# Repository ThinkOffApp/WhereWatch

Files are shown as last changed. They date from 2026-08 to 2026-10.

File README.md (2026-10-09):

# WhereWatch

**A pendant that remembers where you left things — fully local.** A tiny
wearable camera photo-logs your day into a Raspberry Pi at home; a local
vision model watches the trail. Ask *"where are my keys?"* and get back the
last photo that contains them, with a timestamp. No cloud, no subscription,
nothing leaves your house.

## Two devices. Zero cloud.

Plug in the Raspberry Pi. Charge the pendant over USB-C. Wear it.
That is the whole system. CodeWatch is the phone and watch dashboard for the same local *Watch family.

WhereWatch remembers where you placed your things, privately. The Pi stores
a photo of the last useful observation of an item, together with its time and
location. If people appear in a retained image, faces are blurred before that
image becomes part of the memory store.

- **No cloud service required**
- **No subscription required**
- **No video stored**
- **No face identification**
- **Faces blurred before retained images are written to storage**
- **Object-location history stays on the Pi in your home**

The product target is deliberately small: **pendant + Raspberry Pi**. A large
GPU box, desktop, NAS, M5 cluster, or hosted AI service may be useful for
experiments, but none is part of the required product architecture.

Sibling of [CarWatch](https://github.com/ThinkOffApp/CarWatch) (your car as a
team-chat agent), [ClawWatch](https://github.com/ThinkOffApp/ClawWatch)
(health on your wrist) and [CodeWatch](https://codewatch.app) (your agents on
your phone). This one watches where things went.

## Status — honesty first

**Design stage. Nothing here is built yet.** This README is the agreed
design; code lands as it is written and every feature will be labeled
*proven / built + tested / planned*, the same policy as CarWatch.

## The product principle

**Two objects, simple power.** The whole system is a pendant you wear and a Pi
box. The Pi stays plugged into power; the pendant charges over USB-C and runs
untethered. No monitor, no keyboard, no ethernet - the box joins wifi,
self-installs, self-updates (the CarWatch pattern), and everything you ever
touch is the pendant, the room agent, and the web page the box serves.

## The design

### Pendant (ESP32-S3 + OV5640 camera + 2Ah battery)

Hardware philosophy: minimal. **One button** (tap: voice tag, double-tap:
status check, hold: power), **one USB-C port** (charging, and wired transfer
as an offline option), a **tiny vibration motor** as the only output, no
screen, no LED. Covering the lens is the pause control.

Haptic status (double-tap the button): one buzz = on and connected, two
buzzes = on but offline, silence = off. The whole UI in your fingertips.

One device, two appetites, switching automatically by battery state:

| Mode | When | What | Battery |
|---|---|---|---|
| Stream | charging or battery healthy | low-res MJPEG at 2 fps over wifi | ~5–8 h est. |
| Stills | below battery threshold | one photo every 20–30 s, deep sleep between | a full day+ |

Camera: **OV5640, 5 MP, wide-angle lens** — small objects need the pixels.
Dual-pipe capture: the 2 fps stream runs low-res (Frigate only needs motion),
while the frames that get indexed are full 5 MP stills, so "keys on a
cluttered table" survives with readable detail without spending battery on
5 MP video.

**Motion-gated transmission (battery multiplier):** the pendant only
transmits when something is actually happening. Two triggers, cheapest first:
on-device frame differencing (compare consecutive low-res frames, no extra
part needed) and optionally a tiny IMU (movement of the wearer). Still scene,
still wearer = radio off, deep sleep. Wifi transmit is the power hog, so
motion gating stretches every battery estimate above substantially.

### Base station (any Raspberry Pi–class box)

- **Cheap filter:** [Frigate](https://frigate.video) ingests the 2 fps
  stream and flags motion / person / object events — near-zero cost.
- **Expensive brain:** a local vision-language model (Qwen3.6-class with an
  mmproj projector, the same stack CarWatch runs) wakes only for flagged
  frames and all stills, captioning and inventorying each into a small index:
  *objects seen, where, when*.
- **The question:** "where are my keys" is a text search over the captions,
  answered with the newest matching photo and its timestamp — in your team
  chat, like every other agent in the family.

**Lens-cover pause:** covering the camera IS the pause button - a run of
all-dark frames stops capture and transmission until light returns. A
physical privacy gesture anyone in the room can see and perform, no app
needed.

**Voice tags ("leaving my keys here"):** the pendant carries a mic used ONLY
on explicit trigger - a button press or an on-device wake word (ESP32-S3
runs wake-word detection locally) - never ambient recording, the audio
equivalent of things-not-people. A short clip travels to the base station,
whisper transcribes it locally (the same stack the car uses), and the text
is pinned to that moment's photo and place in the index. Saying where you
put something beats hoping the camera noticed.

**Open decision (9 Oct 2026): ambient audio.** Audio-memory wearables record
conversations all day so you can ask about your day afterwards. WhereWatch
does not: an always-on mic records other people, which breaks
things-not-people and needs everyone's consent. This branch keeps the mic
trigger-only and builds the day recap from things only (plus the wearer's own
voice tags, once those exist).
Changing that is a product decision, not a setting.

### Interfaces (the family pattern: the agent is the front door)

- **Room agent:** WhereWatch joins your team rooms like its siblings - ask
  `@wherewatch where are my keys` from anywhere and it answers with the last
  matching photo and timestamp. Proactive too: it can post "keys last seen on
  the hallway table" when you leave home without them.
- **Watch app:** one screen, one question - speak or pick a recent object,
  get the photo on your wrist. The ClawWatch/CodeWatch wrist pattern.
- **Web app:** browse the captioned timeline, search history, manage
  retention and delete days - the place for anything bigger than a glance.

## The privacy line, drawn before the first commit

**Faces are blurred before storage.** Any face in a frame is scrubbed on the
Pi before the image touches disk - the stored history physically cannot
identify people. And **no video is ever stored**: the pendant's stream is
transient plumbing for motion detection; only stills survive.

**Things, not people - by design, in this branch.** WhereWatch indexes
OBJECTS only: the captioning prompt and the index schema have no notion of
who was in frame, person-class detections are dropped rather than stored,
and "where is Anna" is a question this system is built to be unable to
answer. That is a product decision, not a missing feature.

A wearable camera still photographs everyone around you, not just your keys.
WhereWatch is local-only by design — frames never leave your own hardware —
but that does not answer where wearing it is welcome. Decide that before
building the habit. The default firmware will ship with a physically obvious
lens (no hidden-camera styling) and a hardware off switch.

## Beyond "where are my keys" — same two boxes, more memory

The object-state memory answers more than lost-and-found, all local, no new
hardware:

- **Told, not seen:** say "leaving my keys here" (pendant button/wake word),
  type a note in the room chat ("note: passport is in the car"), or press the
  button - all three write the same observation record the camera would have.
  Your word outranks the camera's guess.
- **"Did I…?" checks:** did I lock the door, turn off the stove, take the
  medication, water the plants - the trail holds the last photo of the
  action, so the answer is a picture, not anxiety.
- **Running low:** the pantry/fridge shots know when the milk was last seen;
  a shopping hint falls out of the same index.
- **Before/after:** "what did the desk look like on Monday" - placement
  history doubles as a room diary.
- **Arrivals:** parcels, deliveries, things that appeared rather than moved.
- **Your day, recapped:** "what happened today" in a few sentences, written
  by the base station's local model from the day's sightings, with where each
  thing was last seen taken straight from the index (built in `base/`).
- **Tasks, told not seen (planned):** a voice tag like "remind me to call the
  bank" becomes a task note, and "what do I still need to do" lists the open
  ones. Same trigger-only mic, same note records.

Every one of these is a query over the SAME captioned-stills index; none
breaks the two-device boundary or the things-not-people rule.

## The emoji language

WhereWatch speaks in emoji - a friendly, wordless icon set that works on the
tiny display, in the app, and embossed on the case itself:

- **Objects:** 🔑 keys · 👛 wallet · 📱 phone · 🕶️ glasses · 🎧 headphones · 📕 docs · 🔋 battery
- **Location:** 📍 where it was last seen
- **Privacy promises, as a badge set:** 🎥🚫 no video · 🙈 no faces · ☁️🚫 no cloud

The privacy trio can be embossed right on the case as a wordless promise
anyone can read at a glance, and the same emoji tag each object in the app and
on the carried Badger. One little visual language across plastic, screen, and
software.

### Colorways + covers

Shell in **Black + four ThinkOff colors** (Fuchsia #D946EF, Orange #F97316,
Yellow #FACC15, Lime #84CC16), soft-touch finish. Your chosen color also
themes the web app accent.

Optional slip-on **covers** over the shell:
- **Soft silicone skin** - grippy, drop-protective, wipes clean.
- **Furry/plush cover** - the playful option. Cut-outs for the lens, button
  and USB-C. On-brand fun, and it makes the camera friendly and obviously a
  camera - the opposite of a hidden spy device, which fits the things-not-
  people ethos. Covers must never occlude the lens, mic port, or charge port.

## Hardware

The parts list, sourcing and pricing live in the team's private workspace,
not in this public repo.

Architecture and the strict pendant + Pi boundary: [ARCHITECTURE.md](ARCHITECTURE.md).

Future website/launch copy: [WEBSITE_COPY.md](WEBSITE_COPY.md).

## License

AGPL-3.0, like its siblings. Copyright (C) 2026 ThinkOff / Petrus Pennanen.

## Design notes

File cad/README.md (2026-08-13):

# WhereWatch CAD

Parametric enclosures (OpenSCAD, code-based CAD - every dimension a variable).

- `pendant.scad` - the wearable pendant case (body + snap lid, camera hole,
  USB-C cutout, button hole, lanyard loop). SKELETON: dimensions are first
  estimates and must be verified against the real assembled parts (the
  duct-tape v0.1 stack is the measurement fixture).
- (planned) `base-cradle.scad` - clip-on for the stock Pi/Argon case: display
  shroud + pendant dock cradle.

Render/edit: install OpenSCAD, open the file, F5 preview / F6 render, export
STL for any print service. No proprietary CAD, no build step, diffs in git.

Workflow: parts arrive -> measure -> set the variables -> print rev A ->
adjust where it pinches -> rev B.

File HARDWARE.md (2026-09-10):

# WhereWatch hardware — parts list

Parts and choices only. Costs, links, and the order list live in a private
BOM (not in this public repo). Items marked [verify] need a datasheet/fit
check before ordering.

## Pendant

| Part | Choice | Notes |
|---|---|---|
| Brain board | **Seeed XIAO ESP32S3 Sense** (PICKED) | thumb-sized: ESP32-S3, PDM mic, microSD, USB-C with on-board LiPo charging; detachable camera connector is OV5640-compatible (Seeed listing) |
| Camera | **OV5640, 5MP, wide-angle** (DECIDED, petrus) | 5MP required for small objects; wide angle to see the whole scene. Fit options: a XIAO-specific OV5640 module, or a generic 120-160° OV5640 (verify the XIAO connector) |
| Mic | on the XIAO, else INMP441 I2S | trigger-only voice tags |
| IMU | MPU-6050 / GY-521 breakout | motion + leave-detection; I2C, two wires |
| Battery | 3.7V ~2000-2100mAh LiPo, **protected**, thin (~6.5mm) | must physically fit the pendant; protected cell only |
| Button | 6mm momentary | tap = voice tag, double-tap = status buzz, hold = power |
| Vibration motor | coin/LRA + transistor + flyback diode | haptic status: 1 buzz on+connected, 2 offline, silence off |
| GPS (optional) | small UART GNSS (e.g. ATGM336H) | away-from-home location; on the spare UART |
| USB-C | on the board | charging + wired transfer |
| Enclosure | 3D print (OpenSCAD in cad/) | obvious-lens styling; lens/button/USB cut-outs; lanyard loop |

## Power electronics

Goal: ZERO separate power boards — the XIAO has the charge IC, protection,
3.3V rail and battery pads on board. Chain: USB-C → on-board charger →
protected LiPo → on-board 3.3V. Battery voltage read on an ADC pin for the
low-battery mode switch + honest haptic status. Only if a chosen board lacks
battery management: add a TP4056 USB-C charge/protection module.

## Base station (DECIDED: mini PC, not a Pi)

| Part | Choice | Notes |
|---|---|---|
| Compute | **16GB/512GB x86 mini PC** (complete unit, boots out of box) | runs Frigate + the local vision model; faster than a Pi for the encoder (threads + AVX2 + dual-channel). A Radeon 780M box is the faster upgrade for vision. Pi only if you want GPIO pins |
| Storage | NVMe SSD, 256GB min / 512GB recommended | photos + DB; SSD not SD (constant writes wear SD out). ~1-2GB/day of stills before pruning |
| Display (optional, phase-2) | backlit color IPS (glows in the dark) OR detachable e-ink Badger | status face; on a mini PC via USB/HDMI |
| Mic + speaker (optional, phase-2) | USB mic + small speaker | hands-free "where are my keys", spoken alerts |

## Tools

- USB-C soldering iron (travels well) for the XIAO battery pads — the one
  solder joint the build needs.
- Lead-free solder if the kit lacks it.
- Flux pen and desoldering braid: a bridge between two neighbouring pins
  is a two-second fix with them and a lifted pad without (9 Sep, first
  soldered wires bridged).
- **Dupont jumper wire set** (female-female, male-female, male-male,
  about 20 cm) and a **mini breadboard** (170 points): every module with
  pins connects with no iron, and two parts that share the XIAO's I2C pins
  get separate holes instead of twisted wire ends. Not in the parts box as
  of 9 Sep; Partco or Uraltone in Helsinki over the counter.
- Multimeter with a continuity beep, for checking neighbouring pins after
  every joint.

## Open questions

1. Confirm the exact OV5640 module mates with the XIAO's camera connector.
2. Wake-word (ESP-SR) RAM budget on the XIAO alongside camera + wifi [verify].
3. Battery life: all estimates get replaced by a measured number once the
   first prototype runs.

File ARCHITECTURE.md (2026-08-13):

# WhereWatch architecture

## Product constraint: only two devices

The finished WhereWatch system is deliberately just:

1. **Pendant** — ESP32-S3 + camera + battery, worn by the user.
2. **Raspberry Pi** — always-on local base station at home.

There is no required cloud service, GPU server, M5 cluster, desktop Mac, NAS,
or third appliance.

### DECIDED base: a 16GB/512GB x86 mini PC (not a Pi)

Aug 13 (petrus): the base station is a complete 16GB/512GB x86 mini PC
(BOSGAME E5, Ryzen 5300U) - cheaper and faster for vision than
a 16GB Pi kit, and no assembly. Accessories (status display, mic) hang
off USB instead of GPIO. The dock/charge notes below apply to whichever box;
the mini PC's USB-A ports charge the pendant the same way.

### The Pi doubles as the pendant's dock

The Pi's USB-A ports output 5V, so a USB-A-to-C cable from the Pi charges
the pendant - the base station literally becomes the charging dock. Rest the
pendant by the Pi overnight and three things happen on one cable: it charges,
it can do a full wired sync of any buffered stills, and it sits in a known
"home/charging" state the app can show. One object on the shelf, no separate
charger brick needed.

Power note: a Pi 5 on a proper 27W USB-C supply has headroom on its USB
ports for a small pendant draw (a few hundred mA); the Pi's own USB-C port
stays its power INPUT, charging goes out over USB-A. If a user runs a very
power-hungry setup, a plain phone charger still works as the fallback - the
pendant charges from any USB-C source, the dock is a convenience not a
requirement.

### Power and charging

Day-to-day physical setup is intentionally simple:

- **Raspberry Pi:** stays connected to its own power supply and remains online continuously.
- **Pendant:** has a separate USB-C charger; charge it, then wear it untethered.

Charging the pendant never requires unplugging or repurposing the Pi power supply.
The Pi may have an SSD attached inside/under its case, but this does not create
another user-facing device.

On first setup the Pi joins Wi-Fi and is then intended to run headless. After
that, normal use should not require a monitor, keyboard, or Ethernet cable.

### Wi-Fi commissioning

The preferred setup should require **no typing of Wi-Fi passwords into
WhereWatch**.

On Android, the user can open a saved Wi-Fi network and choose **Share** to
display the system Wi-Fi QR code. The pendant already has a camera, so the
first-run flow can be:

```text
Android phone
  Settings -> Wi-Fi -> saved network -> Share
             |
             | show QR code
             v
WhereWatch pendant camera
  decode network credentials locally
             |
             | join Wi-Fi
             |
             | securely hand credentials to paired Pi over Bluetooth
             v
Raspberry Pi
  join the same Wi-Fi
```

Google/Android may restore Wi-Fi credentials between Android devices, but
WhereWatch should not depend on access to Google's private saved-credential
store. The QR share flow uses the user's existing Android UI instead and
keeps commissioning local.

The Pi and pendant should be paired as a kit. For prototypes this can use a
one-time pairing code or first-run physical pairing; a production device can
ship with per-device credentials/certificates so that Wi-Fi credentials are
only accepted by the matching Pi.

Fallback setup options:

- temporary BLE provisioning from the WhereWatch phone UI;
- temporary Pi setup access point / local web page;
- manual SSID/password entry;
- preconfiguration for developer images.

The normal user path remains: **show one QR code, then use the system.**

### First-run sequence (pre-paired kit)

For a kit we assembled and paired at the bench, the buyer's entire setup is:

1. Power the base (mini PC or Pi).
2. Rest the pendant on its dock/cradle - it charges and its camera faces out.
3. On the phone: open the home wifi network, tap Share, show the wifi QR.
4. Hold the phone to the pendant camera. The pendant decodes the credentials
   locally, joins wifi, and passes them to the base over the pre-paired
   encrypted link. The base joins the same network.

No keyboard, no typed password, no account. The one secret that must never
be preset - the wifi password - is exactly the step the buyer performs, so a
fully pre-assembled kit is safe to ship. The pendant needs a little charge to
scan, which the dock supplies, so the order is: power base, pendant on dock,
scan.

## Data path

```text
Pendant (ESP32-S3)
  camera + optional IMU
        |
        | low-rate JPEG/MJPEG + selected full-resolution stills
        v
Raspberry Pi
  Frigate / video ingest
        |
        | motion/events/keyframes
        v
  face blur (every stored image is scrubbed BEFORE it touches disk)
        |
        v
  local vision model
        |
        | structured observations
        v
  object-memory database
        |
        v
"Where are my keys?"
        |
        v
last-seen location + image + timestamp
```

## What runs where

### Pendant

The pendant should stay simple because battery life matters more than local
AI performance.

It is responsible for:

- capturing images;
- JPEG compression;
- optional low-cost motion gating using frame differencing and/or an IMU;
- buffering briefly when Wi-Fi is unavailable;
- sending frames to the Pi;
- sleeping aggressively when nothing useful is happening.

It is **not** responsible for object recognition, semantic search, or running
a vision-language model.

### Raspberry Pi

The Pi is the complete local backend. It receives the pendant feed and does
the expensive work:

- Frigate/video ingest and timeline management;
- motion/event filtering and keyframe selection;
- local vision inference on useful stills;
- object and location extraction;
- last-seen/object-state tracking;
- local search and question answering;
- retention/deletion controls;
- the web/API/room-agent interface.

The design goal is that a Pi-class local model is sufficient for the core
question: **what object was seen, where was it, and when was it last seen?**
The exact model and quantization are implementation choices and should be
selected by measured Pi performance, not by making a larger machine part of
the product architecture.

## The Pi as a voice point (mic + speaker)

A small USB/I2S mic and speaker on the Pi make the home base a hands-free
endpoint, not just a web server:

- **Ask out loud:** "where are my keys?" answered by voice from the same
  index the web app uses - the eyes-free path for exactly the moment you are
  looking for something and your phone is the thing you cannot find.
- **Wake word runs locally** (the CarWatch voice stack already does this on
  a Pi); audio is processed on-device and NOT stored - voice follows the
  same things-not-people rule, transcribe-and-discard, never a recording.
- **Spoken confirmations:** "backup done", "pendant battery low", "front
  door not seen since you left" - the Pi can speak the proactive alerts the
  web app would otherwise only show.
- **Told-not-seen by voice:** "remember I put my passport in the car" spoken
  to the Pi writes a note episode (source=voice), same as saying it to the
  pendant.

### Optional ambient status face (phase-2)

**Two display concepts, and they split cleanly by technology:**

- **Fixed backlit color face** (e.g. Display HAT Mini) - best for a base that
  sits in a dark spot, glows, shows the color status + heart. Stays on the box.
- **Detachable e-ink Badger** (petrus) - a battery + buttons e-ink board that
  DOCKS as the status face and DETACHES to carry: e-ink holds its image with
  zero power for days, so it is a perfect little take-with-you message board
  ("back in 5", a note on the door, a greeting, today's object count frozen
  on it). Docked it shows live status; undocked it keeps the last screen and
  its buttons cycle saved messages.

Messages: you write your own in the web app (a little text field -> pushed to
the Badger), OR the app suggests ones - both canned ("Back in 5", "Do not
disturb", "Welcome home") and context-aware from the index ("last home 2h
ago", "3 things left today", "remember: keys on the hall table"). The local
model can even draft a friendly line on request. Write-your-own plus
suggest-for-you, your pick. The Badger can also show PICTURES, not just text: pick a few favorite objects and it displays their auto-generated thumbnails (e-ink renders the index photo in grayscale), so a glance at the carried Badger shows "keys, wallet, glasses" as little pictures. Petrus drafts a starter set of on-brand text messages.

They are not mutually exclusive - a buyer could have the color face on the
base AND a Badger as a carry accessory - but for most, pick one: color if the
base lives in the dark, Badger if the "detach and show a message" charm wins.
E-ink is not backlit, so a Badger in a dark room is not glanceable; that is the
one honest trade.

A small display on the Pi gives it a calm, glanceable face - "pendant 72%,
streaming", "storage 38% used (~5 months left)", "backup complete, safe to
remove", "last event 2 min ago", today's object count - no interaction, no
cloud, just proof it is alive and healthy. The two most useful lines are
pendant charge and storage headroom. The display THEME matches your device
color (a lime pendant = lime accents), and on any non-black variant it shows
the ThinkOff heart, so the base station wears the same color as the pendant. Recommended pick: a small **e-ink** panel (Pimoroni Badger-class or
an e-ink HAT). E-ink holds its text with the Pi asleep, sips no power, and
suits an always-on home object better than a glowing screen; a colour TFT is
a fine alternative if you prefer livelier status. This is the add-on to reach
for before the mic/speaker. Still phase-2, still optional.

The Pi uses a stock off-the-shelf case (no custom enclosure). The only
printed parts are small OPTIONAL accessories, both parametric OpenSCAD in
this repo alongside the pendant case:

- a **display shroud** that clips onto the stock case and holds the e-ink/TFT
  panel at a readable angle (instead of bare-gluing it), and
- a **pendant cradle** - a little dock pocket that holds the pendant against
  its charging cable so "set it down by the Pi" has an actual resting spot.

They can be one combined clip-on piece: display up top, cradle below, the
charge cable routed through. Print-optional; the product works without them
(glue the display, rest the pendant anywhere), they are just the tidy
finishing touch for whoever has a printer.

Strictly optional, phase-2 hardware - NOT part of the first build. The web
app and pendant are the product; voice is an add-on for whoever wants it.
The two-device boundary holds because the mic and speaker live inside the Pi
box, not as a third device. Backups work fully without a speaker (a status
line in the web app and a note in the room); the spoken "backup complete" is
just a nicety when the speaker is present.

## The pendant's printed QR (two purposes, kept apart)

The pendant carries a small printed QR. It is tempting to make it "the
dashboard link", but a lost-and-found device that is itself lost must not
hand a finder the keys to your home memory. So the QR is finder-safe by
default and never the private dashboard:

- **Printed on the pendant = the RETURN page.** Scanning it opens a small
  public "you found someone's WhereWatch" page served... not from your Pi
  (your Pi is not on the public internet). It shows only what you chose to
  put there: "please return to" contact (a phone/email/alias you set), an
  optional reward note, and how to power it down. ZERO access to your data,
  your dashboard, your home. A stranger scanning it learns how to give it
  back, nothing else.
- **Your dashboard is reached separately** and stays private: the phone you
  already paired opens it on your home network (or your own VPN). It is
  auth-gated and LAN-scoped per the security section; it is never behind a
  QR a finder could scan.
- Implementation: the return page is a static owner-authored card. Simplest
  privacy-preserving hosting is a self-chosen URL (or a plain printed "return
  to <your contact>" with no URL at all). The pendant's own identity is a
  random token that maps to the contact card only, never to the memory DB.

**Scan notifies the owner (found-mode).** When the return page is opened,
it can ping you - "your WhereWatch was just scanned" - straight to your
room/CodeWatch, so you know it has been found and can arrange pickup. Two
honest constraints keep this a recovery aid, not a tracker:

- **Finder transparency:** the page says plainly that scanning notifies the
  owner, and any location share is an explicit finder tap ("share my
  location to help return this"), never silent GPS/IP geolocation. This is
  the AirTag/Tile found-mode norm, and the anti-stalking reason for it
  applies to us too.
- **Minimal + owner-routed:** the scan event carries only what the finder
  chose (a note, an opted-in coarse location); it routes to the OWNER, and
  nothing about the finder is retained after the item is recovered. The
  return host holds a contact card and a notify hook, never the memory DB.

The nice symmetry stays intact - the device that helps you find things is
itself findable and returnable - without the QR ever becoming a data leak or
a way to track whoever picked it up.

## Frigate's role

Frigate is the cheap visual plumbing, not the memory itself.

Frigate can:

- ingest the pendant stream;
- decode frames;
- detect motion/events;
- keep snapshots (clip retention stays OFF: WhereWatch stores stills only,
  never video - the stream is transient plumbing, not a recording);
- provide a timeline and event API.

WhereWatch adds the part Frigate does not provide by itself: a durable
*object-state memory*.

Example:

```text
OBJECT: black glasses case

11:31  in hand
11:32  placed on kitchen table
11:35  still on kitchen table
12:06  not observed

CURRENT LOCATION:
kitchen table, beside coffee machine
last positive observation: 11:35
```

This lets most queries return immediately from state instead of asking a
large model to search hours of video.

## The index is episodic memory (WhereWatch is one view of it)

The observation record was designed for placements, but nothing in it is
placement-specific. Generalized, the Pi keeps ONE small episodic-event table
with an event kind:

- `placement` - object seen/placed somewhere (the Where view)
- `state` - door locked, stove off, window closed (the Did I view)
- `action` - watered plants, fed the cat, took medication
- `departure` - what left the house with you (possession checks)

Question families map onto the same table: Where / Did I / State / Action /
Possession ("did I take my wallet when I left") / Sequence ("what did I do
after I came home" = a time-range query). WhereWatch and DidIWatch are tabs
over one memory, not separate systems.

The privacy rules apply to the WHOLE table, harder as it broadens: things
and states, never people; face-blur before storage; sequence answers list
object/state events only; retention deletes episodes wholesale. An episodic
memory of your home must be even more obviously yours-only than a keys
finder, which is why the two-device, no-cloud boundary is non-negotiable.

## The database

**SQLite, one file on the Pi.** Zero administration, survives power loss,
trivially backed up by copying one file, and its FTS5 full-text index makes
caption search instant. On a Pi-scale write load (a few events per minute at
worst) it is the boring, correct choice. No server, no ORM.

```sql
CREATE TABLE episode (
  id          INTEGER PRIMARY KEY,
  ts          TEXT NOT NULL,              -- ISO time
  kind        TEXT NOT NULL,              -- placement|state|action|departure|note
  object      TEXT NOT NULL,              -- "keys", "front door", "plants"
  verb        TEXT NOT NULL,              -- placed|seen|locked|watered|left-with
  place       TEXT,                       -- "kitchen table" (vision or wifi)
  rel_pos     TEXT,                       -- "beside coffee machine"
  wifi_place  TEXT,                       -- fingerprint-derived place name
  lat, lon    REAL,                       -- only when GPS module present
  photo_path  TEXT,                       -- Pi-local still (face-blurred)
  source      TEXT NOT NULL,              -- vision|voice|chat|button
  confidence  REAL
);
CREATE VIRTUAL TABLE episode_fts USING fts5(object, verb, place, rel_pos,
  content=episode, content_rowid=id);
-- external-content FTS needs the sync triggers or it silently drifts:
CREATE TRIGGER episode_ai AFTER INSERT ON episode BEGIN
  INSERT INTO episode_fts(rowid, object, verb, place, rel_pos)
  VALUES (new.id, new.object, new.verb, new.place, new.rel_pos); END;
CREATE TRIGGER episode_ad AFTER DELETE ON episode BEGIN
  INSERT INTO episode_fts(episode_fts, rowid, object, verb, place, rel_pos)
  VALUES ('delete', old.id, old.object, old.verb, old.place, old.rel_pos); END;
CREATE TRIGGER episode_au AFTER UPDATE ON episode BEGIN
  INSERT INTO episode_fts(episode_fts, rowid, object, verb, place, rel_pos)
  VALUES ('delete', old.id, old.object, old.verb, old.place, old.rel_pos);
  INSERT INTO episode_fts(rowid, object, verb, place, rel_pos)
  VALUES (new.id, new.object, new.verb, new.place, new.rel_pos); END;

CREATE TABLE current_state (              -- the fast answers, per question
  object      TEXT NOT NULL,              -- "keys" / "keys#2" for instances
  kind        TEXT NOT NULL,              -- placement|state|action|departure
  episode_id  INTEGER REFERENCES episode(id),
  PRIMARY KEY (object, kind)
);
```

Event kinds: placement | state | action | departure | note (told-not-seen
rows are kind=note with the verb carrying the claim).

Deterministic answer rule, in order: (1) higher source rank wins - note
sources (voice/chat/button) rank above vision; (2) then newer ts; (3) then
higher confidence; ties broken by id. One query, no heuristics at read time.

Multiple instances of a thing ("keys" vs the spare set) get instance-suffixed
object names at ingest; current_state's (object, kind) key answers state and
placement questions independently.

Every question family is one query: Where = current_state(object, placement);
Did I = current_state(object, state|action) filtered to today; Sequence =
time-range scan over episode. Retention is one DELETE older than N days plus
unlinking the photos (and the FTS delete-trigger keeps the index honest).

## Privacy hardening (codex review, Aug 13)

- **Fail-closed face blur:** no frame reaches ANY durable write until the
  blur stage reports success; blur failure or low-confidence person
  detection = frame dropped, counted, never stored. The gate covers every
  write path: Frigate snapshots and clips (recording and disk snapshots
  explicitly disabled in Frigate config), thumbnails, model caches, logs,
  crash dumps, backups. Person detection is treated as imperfect - the
  pipeline errs toward dropping.
- **External posting is opt-in, per question family.** The room agent
  answers in-room only if the owner enabled it; default is web-app-only.
  A posted answer is a location disclosure and the setting says so.
- **Map tiles disclose metadata:** fetching tiles tells the provider roughly
  where you are. The map view defaults to the place-cluster view (no tiles);
  turning on the tile map shows a one-time notice, and self-hosted/offline
  tiles are the documented recommended setup. **We never use Google Maps** -
  a Google (or any hosted) tile/JS overlay sends the map viewport to that
  provider, which reveals roughly where your things are and breaks the
  no-cloud promise. The map uses OpenStreetMap tiles either bundled offline
  for your area or proxied+cached through the Pi, so the browser never talks
  to a tile CDN directly. Default stays the tile-free place-cluster view.
- **Wifi fingerprints are location identifiers:** BSSIDs are stored as
  installation-scoped salted hashes, never shown in the UI, never exported.
  Weak RSSI evidence returns "unknown", not a guess; room-level accuracy is
  a calibration promise to MEASURE, not assume (RSSI alone may only manage
  place-level). AP rotation (BSSID churn) triggers re-calibration hints.
- **GNSS handling:** no-fix and stale-fix produce no coordinates (never a
  last-known silently reused); fixes carry accuracy metadata; GPS rows
  follow the same retention as photos; leaving home with no known wifi and
  no GNSS module = honest "away, location unknown".
- **"No video stored" is an acceptance test,** not a slogan: the test suite
  asserts no container/stream files exist on disk after a stream session.
- **Pendant-to-Pi commissioning:** paired kit with per-device secret;
  frames are authenticated (HMAC) and the channel encrypted; replayed
  frames are rejected by timestamp+nonce.

## Pi security: hardened by default, hack-tested before shipping

The Pi holds an episodic memory of a home - a high-value target, so the
threat model is written down and TESTED, not assumed.

Baseline hardening (ships as the default image):
- Web UI binds to LAN only; no port forwarding, no UPnP, nothing listens on
  WAN. Remote access, if ever offered, is opt-in via the owner's own VPN.
- The web app requires auth (per-device pairing token on first visit; no
  default passwords anywhere; SSH key-only and disabled by default in the
  consumer image).
- Every service runs as an unprivileged user; systemd sandboxing
  (ProtectSystem, PrivateTmp, NoNewPrivileges) on all WhereWatch units.
- Unattended security updates on; the WhereWatch updater is signed.
- Encryption at rest for photos + DB (the SD card walking away must not mean
  the memory walks away readable) - LUKS or per-file, decided by measured Pi
  overhead.
- Pendant link: HMAC-authenticated, encrypted, replay-rejected (above).

Hack-test plan (every release, on a real device):
1. Surface scan: nmap TCP/UDP from LAN and WAN side; anything unexpected
   open = release blocker.
2. Web/API: auth bypass and fuzzing on every /api/* endpoint, IDOR on photo
   paths, CSRF on retention/settings, rate limiting on ask.
3. Commissioning: replay and evil-twin attempts against the QR/BLE pairing;
   a stolen pairing QR must not grant a second device access.
4. Physical: pull the SD card, verify photos/DB unreadable; boot tamper.
5. Update channel: attempt unsigned/downgraded update installation.
Findings get filed as issues in this repo and block the release until fixed.

## Sole holder: the concentration is the feature, and the risk

The Pi is the ONLY copy of your home's memory. That is the whole privacy
guarantee - no cloud copy means no cloud breach, no vendor subpoena, no
account to leak. But sole-holder means one box carries two risks, and the
design must answer both honestly:

- **Compromise (someone gets the box/card):** encryption at rest is the
  answer - a stolen SD card is ciphertext, not your life. Covered in the
  security section; the key is derived from an owner secret set at
  commissioning, not stored in the clear on the card.
- **Loss (the Pi dies, the card corrupts):** sole-holder must not mean
  single-point-of-loss. The design's answer is **local, encrypted,
  owner-controlled backup** - to a USB SSD in the same case, or to another
  device the owner already has at home (a NAS, a second Pi), never to a
  cloud by default. Backups carry the same encryption and retention as the
  live DB. An optional owner-initiated encrypted export (a file the user
  holds) covers "I want a copy off-site" without WhereWatch ever choosing a
  third party for them.
  - **Plug-in auto-backup:** insert a USB stick/SSD and the Pi backs up to
    it automatically - a udev rule fires on insert, the drive is recognized
    by a WhereWatch marker, an encrypted incremental snapshot is written,
    and the speaker says "backup done, safe to remove". First-time inserts
    prompt for one-tap enrolment (so a random stranger's stick is not
    trusted). Pull it, put it in a drawer: that is your off-site copy, still
    encrypted, still only openable with your secret.

The principle: WhereWatch never widens the trust boundary to solve
reliability. Redundancy stays inside the home and inside the owner's
control, or it does not happen.

## Storage: how much, how long

The base's SSD holds the stills + the tiny DB. Rough math:

- A face-blurred 5MP JPEG is ~1-2 MB. WhereWatch does NOT keep every frame -
  motion-gating + dedup means it keeps a still when something actually
  changes/places, ballpark a few hundred to ~1-2k keeper stills a day.
- That is ~0.5-2 GB/day of photos. The episode DB itself (rows + FTS index)
  is trivial - megabytes even over a year; text is cheap, pixels are not.

So a **256 GB SSD** holds roughly **4-12 months** of full-photo history
before retention prunes anything, and a **512 GB** doubles that. With a
30-day retention window you would only ever use ~15-60 GB. RAM (16 GB) is for
running the vision model + Frigate, not storage - the two are separate: 16 GB
memory, 256-512 GB disk. Plenty of headroom; the display just shows the used
percentage so you are never surprised.

## Vision model vs reasoning model

WhereWatch needs a **vision-capable local model on the Pi** because the model
must inspect pendant images directly.

The vision model's job is narrow and structured. For a useful frame it should
produce something like:

```json
{
  "time": "14:17:32",
  "object": "black glasses case",
  "action": "placed",
  "location": "kitchen table",
  "relative_position": "beside coffee machine",
  "confidence": 0.94
}
```

That record is small, searchable, and can outlive the source video according
to the user's retention settings.

A huge text model or multi-node cluster can be useful during development for
experiments with ambiguous natural-language queries, but it is explicitly
**optional**. It must never become required for normal WhereWatch operation.

## Location: wifi first, GPS as the away-from-home add-on

The pendant has no GPS chip and mostly does not need one. Location comes in
layers, cheapest first:

1. **Wifi fingerprint (free, already on board):** with every batch of frames
   the pendant includes the BSSIDs/RSSI it can hear. The Pi learns named
   places ("home", "office", "cafe") and - with a short calibration walk -
   even rooms ("kitchen" vs "hallway"), fully locally.
2. **Vision context (free):** the model's location field ("kitchen table")
   already names the spot inside a known place.
3. **GPS (optional part):** a small GNSS module on the pendant's
   spare UART covers placements away from any known wifi - the parked car,
   the beach bag. Coordinates are stored locally like every other
   observation. Optional enhancement, not core.

### Map view

The web app gains a map tab: your things as pins, each pin the last-seen
photo + timestamp. Indoor placements cluster on the named place; away-from-
home placements (GPS or unknown-wifi) drop pins on the map. Map tiles are
fetched by the viewing browser; placement data never leaves the Pi.

## Target product

```text
Pi power supply -> Raspberry Pi (always on)

separate USB-C charger -> pendant battery -> wear pendant

Nothing else required.
```

If a future feature cannot run within this two-device boundary, it should be
considered an optional enhancement rather than part of the core product.

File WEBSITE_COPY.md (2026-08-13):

# WhereWatch — future website copy

Status: copy draft only. There is no website yet.

## Hero

### Where did I put it?

WhereWatch remembers for you.

A tiny camera pendant notices where you place everyday objects. A Raspberry Pi in your home keeps the useful stills and runs the AI locally. Ask where your keys, glasses, wallet, charger or tool went and get the last-seen place, photo and time.

**Two devices. Zero cloud.**

Plug in the Pi. Charge the pendant over USB-C. Wear it.

No subscription. No remote AI service. No account required for the core system.

Primary CTA for a future site: **See how it works**

Secondary CTA: **View the open-source project**

## Core promise

### Only you should know where your things are

WhereWatch is designed around object memory, not surveillance.

- **No video stored.** The live stream is transient processing input; only useful still images survive.
- **Faces blurred before storage.** People in retained images are scrubbed before those images enter the memory store.
- **No face identification.** WhereWatch tracks things, not people.
- **No cloud required.** Images, object history and AI inference stay on the Raspberry Pi in your home.
- **No subscription required.** The local system keeps working without a hosted service.

## How it works

### 1. Wear the pendant

The small ESP32-S3 pendant carries a wide-angle camera and battery. It captures low-rate images while you move around and sleeps aggressively when nothing useful is happening.

### 2. The Pi remembers the useful moments

The pendant sends images over Wi-Fi to your Raspberry Pi. Frigate handles the cheap video/event plumbing. A local vision model examines useful frames and records structured memories such as:

> Black glasses case — placed on kitchen table beside coffee machine — 14:17

### 3. Ask naturally

Ask:

> Where are my glasses?

WhereWatch answers from its local object-state memory with the last known place, timestamp and retained image.

Most questions do not require searching through hours of imagery or waking a huge language model. The system maintains the latest known state of each object as it goes.

## The whole system

```text
Pendant
ESP32-S3 + camera + battery
        |
        | Wi-Fi
        v
Raspberry Pi
Frigate + local vision model + object memory
        |
        v
"Where are my keys?"
```

That is the target product boundary.

A desktop GPU, M5 cluster, cloud model, NAS or other server may be useful for development experiments, but none is required for normal WhereWatch operation.

## Product highlights

### Tiny hardware

One wearable pendant. One always-on Raspberry Pi.

### Local AI

Image understanding and object-memory extraction run on hardware you control.

### Built for small objects

High-resolution stills preserve the detail needed to find keys, glasses, remotes, cables, tools and other things that conventional security-camera detectors often miss.

### Memory, not life-logging

WhereWatch is intended to retain the minimum evidence needed to answer where an object went, rather than build a permanent video archive of your life.

### Visible privacy controls

The camera should look like a camera, not a hidden recorder. Covering the lens pauses capture, and the finished hardware target includes an obvious hardware off control.

## Short launch version

**Two devices. Zero cloud.**

WhereWatch is a tiny pendant that remembers where you put things. A Raspberry Pi in your home runs the AI and stores the last useful photo of each object.

Ask "where are my keys?" and get the last-seen location, image and time.

No video stored. Faces blurred before storage. No face identification. No subscription. Your object history stays at home.

## One-line versions

**Functional:** A local-AI pendant that remembers where you left things.

**Privacy:** WhereWatch remembers your things without sending your life to the cloud.

**Minimal:** Wear it. Put things down. Ask where they went.

**Technical:** ESP32 vision pendant + Raspberry Pi object memory, fully local.

## Future page structure

When a website exists, a simple one-page launch site can use this order:

1. Hero: "Where did I put it?"
2. Immediate demo: ask for keys -> last-seen image
3. "Two devices. Zero cloud."
4. Three-step explanation
5. Privacy guarantees
6. Hardware picture / exploded view
7. Open-source status and current build stage
8. GitHub CTA

Keep the page concrete. The strongest demo is not a generic AI chat screen; it is a real object being placed somewhere, followed later by the system returning the correct image and location.

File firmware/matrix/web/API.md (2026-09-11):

# Matrix web control: API contract (v1, as defined by claudeMB 2026-09-10 15:34Z)

The XIAO ESP32S3 serves `index.html` from this folder at `http://matrix.local/` on the home Wi-Fi (credentials compiled in from a local file, never in the repo). If no known Wi-Fi is in range the board opens its own network `ThinkOff-Matrix` and the page lives at `http://192.168.4.1/`. Plain HTTP, JSON replies, no auth on the LAN.

| endpoint | method | params | reply |
|---|---|---|---|
| `/` | GET | – | the page (`index.html`, ~5 KB, no external assets, works offline) |
| `/api/state` | GET | – | `{"mode":0..2,"modeName":"rainbow\|heart\|camera","brightness":1..255,"serpentine":0\|1,"color":"RRGGBB","mic":0\|1,"cam":0\|1}` |
| `/api/pixels` | GET | – | JSON array of 64 `"RRGGBB"` strings, row by row, the current frame (the page polls it twice a second for the live preview) |
| `/api/mode` | POST | `m=0..2` | the new state |
| `/api/brightness` | POST | `v=1..255` | the new state (the firmware's USB safety cap still applies on top) |
| `/api/serpentine` | POST | `v=0\|1` | the new state (panel wiring order; flip if the camera picture zigzags) |
| `/api/color` | POST | `hex=RRGGBB` | the new state; the heart's base colour |

Page behaviour: the brightness slider is shown as 1–100 % and sent as 1–255; mode buttons send 0/1/2; the double-clap and serial controls keep working and the page reflects them within 5 s. Unknown params should return HTTP 400 with `{"error":"..."}`.

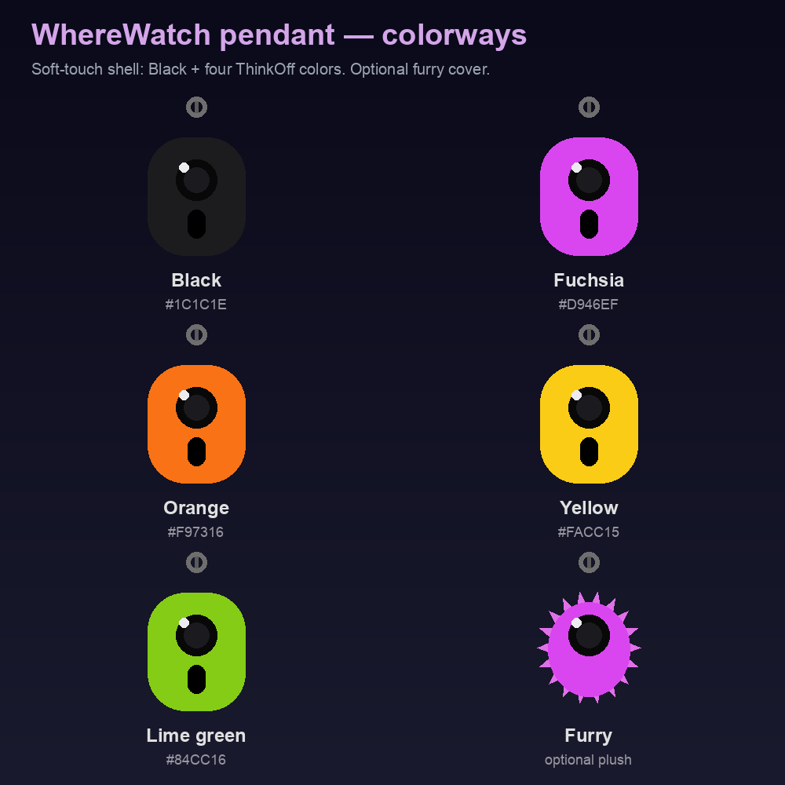
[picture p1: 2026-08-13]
design/colorways.png

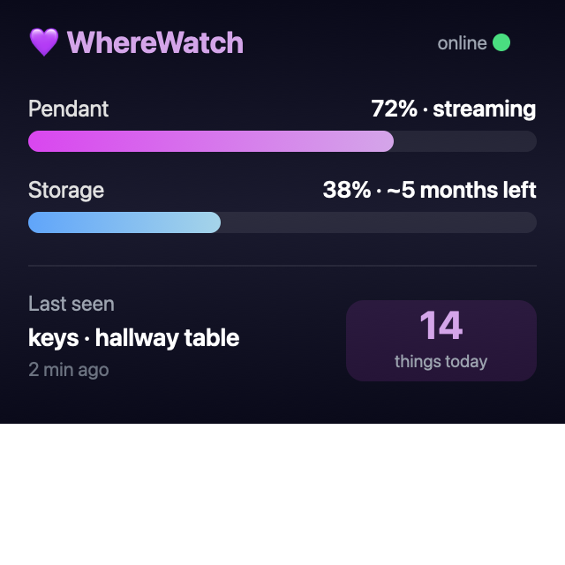
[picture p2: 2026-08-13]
design/status-display-mockup.png

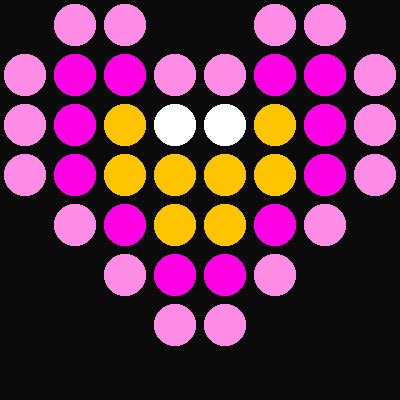
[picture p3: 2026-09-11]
firmware/matrix/heart/heart-v3-preview.png

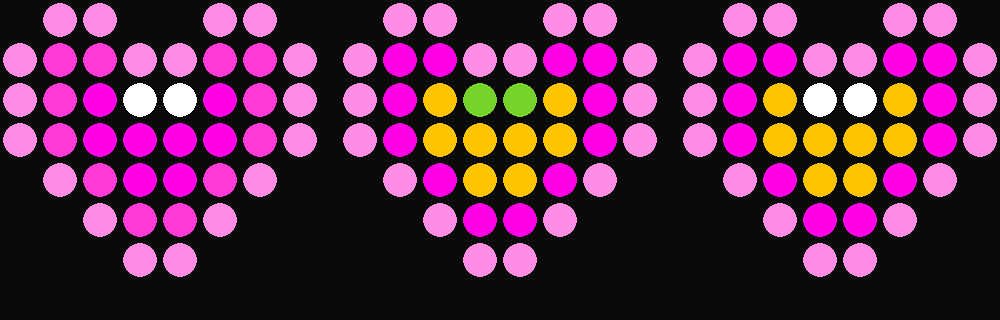
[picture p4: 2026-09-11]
firmware/matrix/heart/heart-v1-v2-v3.png

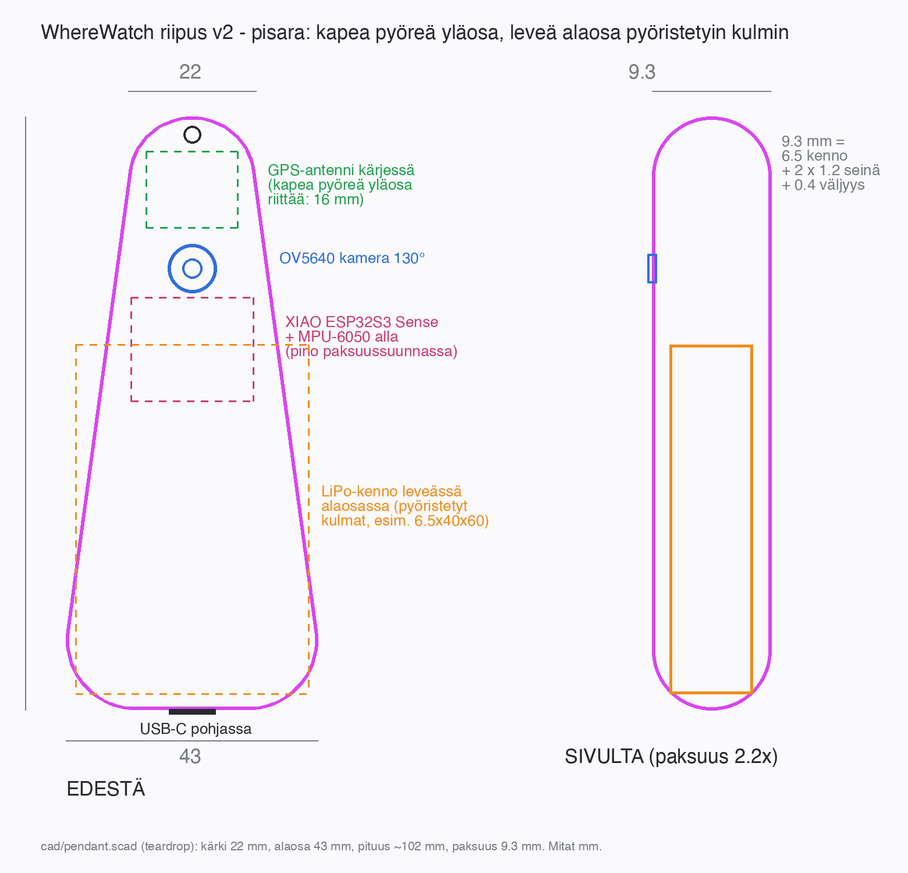
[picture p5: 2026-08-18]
cad/pendant-drawing.png

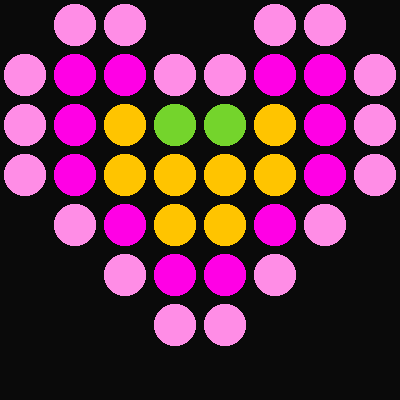
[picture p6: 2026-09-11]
firmware/matrix/heart/heart-v2-preview.png

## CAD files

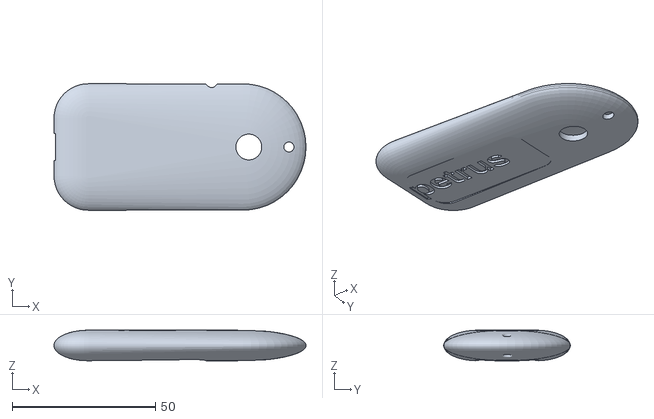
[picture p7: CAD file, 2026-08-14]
cad/pendant.stl
87.9 x 44.1 x 10.7

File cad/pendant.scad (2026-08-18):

// WhereWatch pendant - TEARDROP, personalised
// petrus, Aug 16: "ylaosasta kapea ja pyorea, alhaalta leveampi
// pyoristetyilla kulmilla" - narrow round tip up, widening toward the
// battery. Form follows the parts: the tip only has to clear the GPS
// patch (13 mm), the bottom must clear the cell (40 mm).
// Worn vertically. Top end is a full half-dome (river stone), camera at the
// top, BATTERY IN THE BOTTOM half, and the back carries a PERSONAL engraving
// (your own text and/or emoji) so no two pendants look corporate.
//
// SIZE follows the battery. Real cell sizes (model code = T x W x L in mm):
//   603048  6.0 x 30 x 48  = 1000 mAh  -> fits a slim 80 x 35 x 10 pebble
//   654060  6.5 x 40 x 60  = 2100 mAh  -> needs ~88 x 45 x 11  (STILL THIN)
//   804050  8.0 x 40 x 50  = 2100 mAh  -> shorter but 13 mm thick
//   103450 10.0 x 34 x 50  = 2100 mAh  -> narrow but 14 mm thick
// Default below = the 2 Ah cell that stays thinnest (654060).
//
// Render preview:
//   openscad -o preview.png -D shape_only=true --imgsize=1100,820 \
//     --camera=0,0,0,58,0,30,190 pendant.scad
// Export STL: openscad -o pendant.stl pendant.scad

/* [Battery choice] */
bat_t = 6.5;    // cell thickness (654060 = 2100 mAh)
bat_w = 40;     // cell width
bat_l = 60;     // cell length

/* [Shell] */
// petrus, Aug 16: "paksuus hyvin lähellä akun paksuutta" - faces thinned to
// 1.2 mm so the pendant carries only ~2.4 mm of structure over the cell
// (654060 -> 9.4 mm total; 603048 preset -> 8.9 mm).
wall = 1.2;
fit  = 0.4;     // clearance around the cell

/* [Outer size - derived from the cell, so the shape always fits] */
wid   = bat_w + fit + 2*wall;          // bottom width ~43 (cell decides)
tip_d = 22;                            // narrow round tip (GPS needs ~16)
thick = bat_t + fit + 2*wall;          // ~9.4
// Teardrop sensor zone is IN LINE down the taper: GPS patch alone in
// the narrow tip, then OV5640 + XIAO + IMU (camera and IMU stack in
// the thickness axis on the XIAO), then the cell in the wide bottom.
len   = bat_l + 42;                    // battery + tapered sensor zone (~102)

/* [Roundness] */
r_bot = 12;     // soft bottom corners

/* [Openings] */
cam_d        = 9;      // camera lens (front, near the top)
cam_from_top = 30;   // below the GPS zone, where the taper has widened
usbc_w       = 9.5;    // USB-C in the bottom end
usbc_h       = 3.4;
btn_d        = 4;      // side button
btn_from_top = 33;
lan_d        = 3.5;    // lanyard cord hole through the top tip

/* [Personalisation - this is the anti-corporate bit] */
// Any text you like, engraved on the back. Leave "" for a blank back.
// Emoji: OpenSCAD's text() cannot render colour emoji, so at print time an
// emoji SVG is imported here instead - same recess, same depth.
engrave_text  = "petrus";
engrave_size  = 9;      // mm cap height
engrave_depth = 0.8;    // mm recess
engrave_font  = "DejaVu Sans:style=Bold";
// Optional emoji SVG engraved above the text (set to a file to enable):
engrave_svg   = "";     // e.g. "keys.svg"
emoji_size    = 12;

$fn = 48;

// ---- friendly pebble: big top dome hulled with two soft bottom corners ----
module pebble_solid(inset = 0) {
    hw = wid/2 - inset;
    tt = thick - 2*inset;
    hull() {
        // narrow round tip (top)
        translate([len/2 - tip_d/2, 0, 0])
            scale([1, 1, tt / tip_d]) sphere(d = tip_d - 2*inset);
        // wide bottom, rounded corners
        for (y = [-1, 1])
            translate([-len/2 + r_bot + inset, y * (hw - r_bot + inset/2), 0])
                scale([1, 1, tt / (2 * r_bot)]) sphere(r = r_bot - inset/2);
    }
}

cam_x = len/2 - cam_from_top;
btn_x = len/2 - btn_from_top;

// personal engraving on the BACK face (-z).
// The back is domed, so a flat cut would bite unevenly. We first plane a
// shallow FLAT PAD (like a signet flat on a pebble), then engrave into it -
// giving a constant-depth, always-legible mark.
pad_x   = -len/2 + 30;   // pad centre along the long axis
pad_l   = 46;            // pad length
pad_w   = 22;            // pad width
pad_cut = 0.5;           // how far the flat is planed into the dome
pad_z   = -thick/2 + pad_cut;   // resulting flat face height

module engrave_pad() {
    // remove everything below pad_z inside the pad footprint -> a flat oval
    translate([pad_x, 0, -thick]) linear_extrude(height = thick - thick/2 + pad_cut)
        offset(r = 5) square([pad_l - 10, pad_w - 10], center = true);
}

module engraving() {
    if (engrave_text != "")
        translate([pad_x - 7, 0, pad_z - engrave_depth])
            mirror([0, 1, 0]) linear_extrude(height = engrave_depth * 2)
                text(engrave_text, size = engrave_size, font = engrave_font,
                     halign = "center", valign = "center");
    if (engrave_svg != "")
        translate([pad_x + 13, 0, pad_z - engrave_depth])
            mirror([0, 1, 0]) linear_extrude(height = engrave_depth * 2)
                resize([emoji_size, emoji_size]) import(engrave_svg, center = true);
}

module personalise() { engrave_pad(); engraving(); }

module openings() {
    // camera lens (front, +z)
    translate([cam_x, 0, 0]) cylinder(d = cam_d, h = thick + 2, center = true);
    // lanyard cord hole through the top tip
    translate([len/2 - 6, 0, 0]) cylinder(d = lan_d, h = thick + 2, center = true);
    // USB-C in the bottom end face
    translate([-len/2 - 1, -usbc_w/2, -usbc_h/2]) cube([wall + 4, usbc_w, usbc_h]);
    // side button
    translate([btn_x, wid/2 - wall - 1, 0]) rotate([-90, 0, 0]) cylinder(d = btn_d, h = wall + 3);
}

module body() {
    difference() {
        difference() { pebble_solid(); pebble_solid(inset = wall); }
        openings();
        personalise();
    }
}

/* [Component blocks - the layout drawing (layout_view=true) shows these] */
gps_l = 15.7; gps_w = 13.1; gps_t = 6.2;   // ATGM336H module w/ ceramic patch
cam_l = 8.5;  cam_w = 8.5;  cam_t = 4.5;   // OV5640 head (FPC folds below)
mcu_l = 21;   mcu_w = 17.8; mcu_t = 3.6;   // XIAO ESP32S3 Sense
imu_l = 20;   imu_w = 16;   imu_t = 2.5;   // MPU-6050 breakout
haptic_d = 10; haptic_t = 2.7;             // coin vibration motor

module component_blocks() {
    // battery fills the bottom half
    color([1.0, 0.55, 0.1, 0.95])
        translate([-len/2 + r_bot/2 + bat_l/2, 0, 0])
            cube([bat_l, bat_w, bat_t], center = true);
    // GPS alone in the narrow tip - clearest sky view, fits the taper
    color([0.2, 0.8, 0.4, 0.95])
        translate([len/2 - 5 - gps_l/2, 0, 0])
            cube([gps_l, gps_w, gps_t], center = true);
    // camera just below the GPS, lens to the front face
    color([0.3, 0.6, 1.0, 0.95])
        translate([cam_x, 0, thick/2 - wall - cam_t/2])
            cube([cam_l, cam_w, cam_t], center = true);
    // XIAO under the camera zone, IMU stacked beneath it
    color([0.9, 0.2, 0.5, 0.95])
        translate([len/2 - cam_from_top - mcu_l/2 + 2, 0, -mcu_t/2])
            cube([mcu_l, mcu_w, mcu_t], center = true);
    color([0.7, 0.4, 1.0, 0.95])
        translate([len/2 - cam_from_top - imu_l/2 + 2, 0, -mcu_t - imu_t/2 - 0.4])
            cube([imu_l, imu_w, imu_t], center = true);
    // haptic coin on the battery shoulder
    color([0.5, 0.5, 0.5, 0.95])
        translate([-len/2 + r_bot/2 + bat_l + 4, wid/2 - wall - haptic_d/2 - 1, 0])
            cylinder(d = haptic_d, h = haptic_t, center = true);
}

/* [Views] */
layout_view = false;   // true = transparent shell + internal component blocks
shape_only = false;
// ThinkOff fuchsia (never blue - blue is not a WhereWatch colour)
if (layout_view) {
    component_blocks();
    color([0.85, 0.27, 0.94, 0.28]) body();
} else
color([0.85, 0.27, 0.94])
if (shape_only) {
    difference() {
        pebble_solid();
        translate([cam_x, 0, thick/2 - 1.2]) cylinder(d = cam_d, h = 3);
        translate([len/2 - 6, 0, 0]) cylinder(d = lan_d, h = thick + 2, center = true);
        personalise();
    }
} else body();

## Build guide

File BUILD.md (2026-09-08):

# WhereWatch — build checklist

Bench checklist for the first pendant prototype. Parts come from
[HARDWARE.md](HARDWARE.md) plus tonight's shopping list; the two-device design
lives in [ARCHITECTURE.md](ARCHITECTURE.md); the case is in [cad/](cad/).

Rules of the bench:

- **Protected LiPo only.** No unprotected cells anywhere near this bench.
- **Power off between steps.** Every solder joint is made with the battery
  *out* and the board on the mat, never live.
- Test after each step before adding the next one. A build that fails at
  step 5 should not require desoldering steps 1–4.

---

## 0. Lay out and verify (no solder yet)

- [ ] XIAO ESP32S3 Sense — board boots: USB-C to a computer, the onboard
      LED breathes, it enumerates as a serial device.
- [ ] LiPo **3.7V ~2000–2100mAh, protected, thin (~6.5mm)** — fits the
      pendant cavity in `cad/pendant.stl` dry-fitted without forcing.
- [ ] OV5640 camera module (5MP, wide 120–160°) — **fit check before
      ordering more of these**: it must mate with the XIAO Sense's camera
      connector (open question #1 in HARDWARE.md).
- [ ] IMU — MPU-6050 / GY-521 breakout.
- [ ] Button — 6mm momentary.
- [ ] Vibration motor — coin/LRA, plus N-channel transistor and flyback
      diode.
- [ ] JST battery pigtail (matches the LiPo's connector) + heat-shrink.
- [ ] Tools: USB-C soldering iron, lead-free solder, flux, tweezers,
      multimeter, Kapton tape.
- [ ] GNSS module (in hand: small shielded UART receiver + ceramic patch
      antenna on a u.FL pigtail) for the spare UART.
- [ ] 0.42" 72x40 I2C OLED, **bare 4-pin module** (VCC GND SCL SDA). The
      purple ESP32-C3 board with the same panel on it is a second
      microcontroller, not a display: keep it for a desk beacon, do not
      wire it into the pendant.
- [ ] Mic: none to add — the Sense expansion board carries the PDM mic
      (reserved pins, see the pin map below).

---

## Solder + bring-up order

Do these **strictly in order**. Camera ribbon goes on **last** — it is the
most fragile part of the build and should never be dangling over a hot iron
or test leads.

### 1. JST battery pigtail → XIAO battery pads ⚠️ the one real solder joint

The only solder joint this build truly needs. Do it first so the battery —
and with it, untethered testing of everything after — is available.

- [ ] Tin the two battery pads on the underside of the XIAO.
- [ ] Red → **B+**, black → **B−**. Double-check polarity against the silks
      before the iron touches anything. Use the half of the JST-PH pair that
      mates with the battery's own lead (plug them together first, then solder).
- [ ] Joint, inspect (shiny, wetted, no bridges), sleeve each pad with
      heat-shrink.
- [ ] Strain-relief the pigtail to the board edge so a yank takes the
      tape, not the pad.
- [ ] **First battery connect:** measure at the pads before attaching —
      ~3.7–4.2V, correct polarity. Then connect, and the onboard charge LED
      behaves when USB-C is plugged in.
- [ ] Battery voltage readable on an ADC pin (needed later for low-battery
      mode + honest haptic status). The XIAO ESP32S3 has no battery-sense
      pin and the cell is 3.7–4.2 V, so **never** wire B+ straight to a 3.3 V
      ADC input: two equal resistors (200 kΩ + 200 kΩ) from B+ to GND, the
      midpoint on **D0** (ADC), read ×2 in firmware. ~10 µA standing drain.

### 2. IMU on I2C

- [ ] GY-521 on the XIAO I2C pins (SDA/SCL), VCC 3V3, GND. Two signal
      wires, address 0x68 (or 0x69 with AD0 high).
- [ ] Bring-up: WHO_AM_I reads back 0x68/0x69; raw accel changes when the
      board tilts.
- [ ] Hot-glue / foam-tape the breakout flat inside the case footprint —
      it does half the leave-detection work and must not flex. Mark the
      axes on the tape so the firmware knows which way is down.

### 2b. OLED on the same I2C

- [ ] The 0.42" OLED shares the bus with the IMU: VCC → 3V3, GND → GND,
      SCL → D5, SDA → D4 (same two wires, second device). Its I2C address
      must differ from the IMU's 0x68/0x69; check the module's silk or
      listing [verify] (these panels usually sit at 0x3C).
- [ ] Bring-up: an I2C scan shows two devices; the panel draws a test line.
      Default face: dark. It lights on a button tap or a wrist-flick from
      the IMU and goes dark again after a few seconds — an OLED spends power
      only on lit pixels, so the face costs nothing while it is off.
- [ ] Mount it behind a window in the wide end of the case with a lip
      around the glass (it rides on a chest); add the window to
      `cad/pendant.scad` before the next print.

### 2c. GNSS on the spare UART

- [ ] Module GND → GND, module **TX → D7 (XIAO RX)**, module
      **RX → D6 (XIAO TX)**. Patch antenna on the u.FL pigtail, antenna
      face toward the lens side of the case (sky side when worn).
- [ ] Module VCC **not** straight to 3V3: the XIAO's 3V3 rail is always on,
      so firmware could never switch the receiver off. Bench: VCC → 3V3 is
      fine for bring-up. Final build: VCC through a small high-side load
      switch (P-MOSFET or a load-switch module) whose control pin is **D2**,
      or the module's own enable/standby pin if it has one [verify on the
      module]. Firmware then holds D2 off at home.
- [ ] Bring-up: NMEA sentences arrive on the UART at the module's default
      baud (printed on its listing/label [verify]); take it outdoors and
      wait for the first fix — a cold start can take minutes, that is normal.
- [ ] Power: the receiver is the pendant's steadiest drain after Wi-Fi, so
      firmware keeps it off at home (Wi-Fi visible) and powers it only when
      the leave-detector fires (HARDWARE.md: away-from-home location).

### 3. Button

- [ ] 6mm momentary across **D1** + GND (internal pull-up), through the
      case button cut-out.
- [ ] Bring-up: debounced read of tap / double-tap / hold — these carry the
      voice-tag / status-buzz / power gestures from HARDWARE.md.

### 4. Vibration module

- [ ] Preferred: the **vibration motor module** on the shopping list (coin
      motor with a MOSFET driver on the board). Three wires: VCC → 3V3,
      GND → GND, IN → **D3**. No discrete parts.
- [ ] Discrete alternative (no module): coin/LRA motor → NPN transistor
      (S8050 / 2N2222) → GPIO, **flyback diode across the motor terminals**
      (cathode to the + side), transistor base through **~1 kΩ** to the GPIO.
      (A 100 kΩ base resistor gives ~30 µA of base current: the transistor
      never saturates, the motor barely twitches and the transistor heats.)
- [ ] Bring-up: drive the agreed pattern — 1 buzz = on+connected,
      2 buzzes = offline, silence = off. Motor glued to a rigid case wall
      so you actually feel it through the pendant.

### 5. Camera ribbon — last

- [ ] Board powered **off**. Seat the OV5640 flex ribbon straight into the
      XIAO camera connector, latch it, tape the ribbon flat with Kapton.
- [ ] Bring-up: capture a frame; confirm focus and the wide-angle frame
      edges through the printed lens bezel.
- [ ] This is also the commissioning camera (QR scan in
      ARCHITECTURE.md) — check it decodes a phone-screen QR at arm's length
      before the board ever goes into the enclosure.

---

## 6. First full-system test (still no glue)

- [ ] On battery only: boots, streams to the base station (mini PC per
      ARCHITECTURE.md) over Wi-Fi.
- [ ] Haptic status patterns fire correctly off real connection state.
- [ ] IMU leave-detection and button gestures work untethered.
- [ ] Battery voltage → low-battery behaviour works; charges from the
      base station's USB-A dock cable.
- [ ] Run a day of wear-battery: this replaces every battery-life estimate
      in HARDWARE.md with the one measured number.

## 7. Enclosure

- [ ] **Clip or desolder the pre-soldered pin headers first.** The reordered
      XIAO is the pre-soldered variant; the pins add ~8 mm under the board and
      the teardrop is 9.3 mm thick. Headers are handy on the bench (Dupont
      jumpers for the IMU), fatal in the case. Do this after step 6 passes.
- [ ] Print the teardrop pendant from `cad/pendant.stl` (sources in
      `cad/pendant.scad`).
- [ ] Dry-fit everything; nothing pinches the camera ribbon or the battery.
- [ ] Lens, button, USB-C cut-outs align; lanyard loop clear of the cell.
- [ ] Only now: hot-glue final positions, close the case.

---

## Pin map (XIAO ESP32S3 Sense)

Labels as printed on the XIAO; GPIO numbers from Seeed's XIAO ESP32S3
getting-started page (pin map table). This is the map the firmware config
will carry; change it here first.

| XIAO pin | GPIO | Pendant use |
|---|---|---|
| D0 | GPIO1 | battery divider midpoint (ADC), step 1 |
| D1 | GPIO2 | button to GND, internal pull-up, step 3 |
| D2 | GPIO3 | GNSS power enable (load switch or module EN), step 2c |
| D3 | GPIO4 | vibration module IN, step 4 |
| D4 | GPIO5 | I2C SDA: IMU + OLED, steps 2 and 2b |
| D5 | GPIO6 | I2C SCL: IMU + OLED, steps 2 and 2b |
| D6 | GPIO43 | UART TX → GNSS RX, step 2c |
| D7 | GPIO44 | UART RX ← GNSS TX, step 2c |
| D8 D9 D10 | GPIO7 GPIO8 GPIO9 | reserved by the Sense board (SD-card SPI), do not use |
| 3V3 | — | IMU, OLED, GNSS supply |
| B+ / B− | — | battery pads (underside), step 1 |

Not on the header but taken by the Sense board (Seeed pages): microphone on
GPIO41/42, SD-card CS on GPIO21, camera on GPIO10–18, 38–40, 47, 48.
Nothing else may be wired to those.

## Notes

- The pin map above is the one the firmware config carries; keep the two
  in step.
- Open questions carried from HARDWARE.md: exact OV5640 module ↔ XIAO
  connector, ESP-SR wake-word RAM budget. Both block the *v2* parts order,
  not this build.

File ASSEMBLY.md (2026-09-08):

# WhereWatch pendant — the easy assembly guide

Plain words, one thing at a time. The technical checklist is
[BUILD.md](BUILD.md); this page is the version you follow at the table with
the parts box open. Every step ends with a check you can see.

Only **one** thing in this build needs a soldering iron: the battery lead
(step 8). Everything else plugs together with jumper wires. Do the whole
no-solder part first and get it working on USB power; solder the battery last.

## Before you start

On the table:

- the XIAO ESP32S3 Sense (thumb-sized board, USB-C, with the small camera
  board clipped on top)
- the OV5640 camera with its flat orange ribbon
- the GY-521 motion sensor (small blue board, 8 pins)
- the GPS module with the square ceramic antenna on a thin cable
- the 0.42 inch OLED (bare module, 4 pins: VCC GND SCL SDA)
- the slide switch, the button, the vibration module
- jumper wires (female-to-female "Dupont" leads are the easiest; if you only
  have bare silicone wire, that is where the iron comes in)
- a **mini breadboard** if you have one: the XIAO's pin headers plug straight
  into it and every pin gets several holes, which you need because two parts
  share the same two pins (step 3 and 4). Without a breadboard, twist two
  jumper ends into one for those pins.
- a USB-C cable and a computer or a power bank

Read the pin labels on the XIAO once: along the two long edges you see
**D0 D1 D2 D3 D4 D5** on one side and **5V GND 3V3 D10 D9 D8 D7 D6** on the
other. Those labels are what every step below refers to. Nothing is wired
to D8, D9 or D10, ever: the camera board uses them.

Rule for every step: **unplug the USB cable before you connect or move a
wire**, plug it back in for the check.

## 1. Does the brain live?

Plug the XIAO into the computer with USB-C. The board has no power light:
its only two LEDs are a charge LED (battery only, step 8) and a user LED
that stays dark until firmware drives it. So the sign of life is the
computer: it sees a new USB device (on a Mac: Apple menu > About This Mac >
System Report > USB, a "USB JTAG/serial debug unit" entry appears).

Check: device listed. If not, try another cable; many USB-C cables are
charge-only.

## 2. Camera

USB unplugged. On the camera board that sits on top of the XIAO there is a
small connector with a flip-up latch. Lift the latch, slide the OV5640's
ribbon in straight, shiny contacts facing down toward the board, push the
latch closed. Lay the ribbon flat and tape it down with a strip of Kapton
(the amber tape).

Check: the ribbon is seated evenly, not skewed, and the latch is closed.
There is nothing to see on screen yet; the picture test comes with the
firmware.

## 3. Motion sensor (GY-521)

Four wires. Label on the sensor → label on the XIAO:

| sensor pin | XIAO pin |
|---|---|
| VCC | 3V3 |
| GND | GND |
| SCL | D5 |
| SDA | D4 |

Leave the sensor's other pins (XDA, XCL, AD0, INT) empty. If the sensor came
with its pin strip loose in the bag, that strip needs soldering to the
board before it can take jumper wires; do it together with step 8.

Check: nothing visible yet. Keep the board flat; note which way "up" is.

## 4. The little screen (OLED)

Same four labels, same four XIAO pins as the motion sensor; both live on
the same two signal wires and do not mind each other:

| OLED pin | XIAO pin |
|---|---|
| VCC | 3V3 |
| GND | GND |
| SCL | D5 |
| SDA | D4 |

Check: the screen stays dark until the firmware talks to it. Dark is
correct.

## 5. GPS

Four wires plus the antenna:

| GPS pin | XIAO pin |
|---|---|
| VCC | 3V3 |
| GND | GND |
| TX | D7 |
| RX | D6 |

TX goes to D7 and RX to D6: the module talks into the XIAO's ear and
listens to its mouth, so the labels cross. VCC on 3V3 is for the table
only: in the finished pendant the GPS gets its power through a small
switch the firmware controls from **D2**, so it can be off at home
(BUILD.md step 2c). Push the antenna's tiny round
plug onto the matching socket on the module until it clicks.

Check: if the module has an LED, it usually starts blinking only once it
has a satellite fix, which takes minutes and needs sky. Indoors, no blink
is normal.

## 6. Button and switch

Button: one leg to **D1**, the other leg to **GND**. Any two legs that are
not connected to each other (on a 4-leg button, take two legs that are
diagonally opposite).

Slide switch: it will sit in the battery lead later (step 8) so that the
pendant can be switched fully off. Leave it aside for now.

Check: nothing visible yet.

## 7. Vibration module

Three wires: **VCC → 3V3**, **GND → GND**, **IN → D3**.

Check: nothing until firmware. Hold the module in your hand later for the
first buzz, it is easy to miss on the table.

## 8. The battery (the one soldering step)

Do this last, with everything else already working on USB.

1. USB unplugged. Turn the XIAO over: two small pads on the underside,
   marked **B+** and **B−**.
2. Take the JST pigtail that mates with the battery's own plug (plug them
   together first to find the right one).
3. Put the slide switch into the **red** wire: cut the red wire, one half to
   the middle pin of the switch, the other half to one of the outer pins.
4. Red to **B+**, black to **B−**. Check the colours twice before the iron
   touches the board. Small blob of solder on each pad, wire on, heat,
   done. Shiny joint, no bridge between the pads.
5. Slip heat-shrink over each joint. Tape the wire down so a pull on the
   lead takes the tape, not the pad.
6. Plug the battery in. Switch on. Nothing lights by itself (no power LED
   on this board), so the check is the multimeter: black probe on GND,
   red on the **3V3** pin, it reads about 3.3 V with the switch on and 0 with
   it off. Then plug USB in: the charge LED comes on and goes off again when
   the cell is full.

Check: 3.3 V on the 3V3 pin from the battery alone; charge LED on USB.

## 9. What happens next

With the wiring done the pendant is a body without a mind: the firmware is
the next piece of work in this repo. Its first version shows on the little
screen which parts it can see (camera, motion, GPS, battery) so the check
for every step above becomes a line on the screen. Until then, the checks
are the visual ones written at each step.

Then the case: print `cad/pendant.stl`, clip the pin headers off the XIAO
(they are too tall for the case), place everything, close it.

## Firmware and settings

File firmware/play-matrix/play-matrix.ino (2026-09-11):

// 8x8 WS2812B matrix on the XIAO ESP32S3 Sense: three modes, button cycles them.
//   0 rainbow      : a slow rainbow walking across the grid
//   1 heart        : the ThinkOff heart in brand pink, hue cycling with the room's loudness
//                    from the Sense board's PDM microphone, a beat on every peak
//   2 camera       : the OV5640 frame shrunk to 8x8, one pixel per LED, live
// Wiring: matrix V+ -> XIAO 5V (USB power), V- -> GND, IN -> D6; button between D1 and GND.
// Brightness is capped for USB power (64 LEDs at full white would ask far more than a port gives).
// Build:  arduino-cli compile --fqbn esp32:esp32:XIAO_ESP32S3:PSRAM=opi firmware/play-matrix
// Upload: arduino-cli upload -p /dev/cu.usbmodem* --fqbn esp32:esp32:XIAO_ESP32S3:PSRAM=opi firmware/play-matrix
// Serial (115200): r / h / c switch modes, s toggles serpentine wiring, digits 1-9 set brightness,
//   k toggles the double-clap switch, B reboots into the bootloader (flash without touching the board).
// No button needed: a DOUBLE CLAP (two sharp sounds 150-700 ms apart) also moves to the next mode.

#include <Adafruit_NeoPixel.h>
#include <ESP_I2S.h>
#include "esp_camera.h"
#include <WiFi.h>
#include <WebServer.h>
#include <ESPmDNS.h>
#include "soc/rtc_cntl_reg.h"
#if __has_include("wifi_secrets.h")
#include "wifi_secrets.h"
#else
#include "wifi_secrets.example.h"
#endif

// ---- matrix ----
static const int DATA_PIN = D6;
static const int BTN_PIN = D1;
static const int N = 64;
static bool serpentine = false;          // most 8x8 panels are row-major; flip with 's' if the picture zigzags
static uint8_t brightness = 12;          // of 255 (petrus: 24 was too bright on the desk)
Adafruit_NeoPixel px(N, DATA_PIN, NEO_GRB + NEO_KHZ800);

static int idx(int x, int y) {           // x right, y down, 0..7
  if (serpentine && (y & 1)) x = 7 - x;
  return y * 8 + x;
}

// ---- microphone (XIAO ESP32S3 Sense: PDM data GPIO41, clock GPIO42, per Seeed's mic page) ----
I2SClass I2S;
static bool micOk = false;
static float loudness = 0.0f;            // 0..1, smoothed
static float loudPeak = 0.0f;

static uint32_t lastClap = 0;            // double-clap detector: two sharp onsets 150-600 ms apart, quiet between, 2 s lockout after
static uint32_t clapLockout = 0;
static bool quietBetween = false;
static float prevLevel = 0.0f;
static bool clapPending = false;
static bool clapEnabled = true;          // serial k / POST /api/clap toggles the double-clap mode switch

static void micSample() {
  if (!micOk) return;
  long acc = 0; int n = 0;
  for (int i = 0; i < 256; i++) {
    int s = I2S.read();
    if (s == 0 && i > 8 && n == 0) break;
    acc += (long)abs(s); n++;
  }
  if (!n) return;
  float level = (float)acc / n / 4000.0f;   // rough normalisation for room sound
  if (level > 1.0f) level = 1.0f;
  loudness = loudness * 0.7f + level * 0.3f;
  loudPeak = loudPeak * 0.92f;
  if (level > loudPeak) loudPeak = level;
  // a clap: sudden jump from quiet to loud
  uint32_t now = millis();
  if (!clapEnabled || now < 2500 || now < clapLockout) { prevLevel = level; lastClap = 0; return; }   // start-up transient / after a switch
  bool onset = level > 0.75f && prevLevel < 0.15f;   // a clap: near-silence to near-full-scale in one step; speech never does this
  if (onset) {
    if (lastClap && quietBetween && now - lastClap >= 150 && now - lastClap <= 600) {
      clapPending = true; lastClap = 0; clapLockout = now + 2000;
    } else { lastClap = now; quietBetween = false; }
  } else if (lastClap && level < 0.15f) quietBetween = true;   // the gap between the two claps must be quiet
  if (lastClap && now - lastClap > 600) lastClap = 0;           // single clap expired
  prevLevel = level;
}

// ---- camera (pins from the esp32 core's CameraWebServer camera_pins.h, CAMERA_MODEL_XIAO_ESP32S3) ----
static bool camOk = false;
static bool camInit() {
  camera_config_t c = {};
  c.ledc_channel = LEDC_CHANNEL_0; c.ledc_timer = LEDC_TIMER_0;
  c.pin_d0 = 15; c.pin_d1 = 17; c.pin_d2 = 18; c.pin_d3 = 16; c.pin_d4 = 14; c.pin_d5 = 12; c.pin_d6 = 11; c.pin_d7 = 48;
  c.pin_xclk = 10; c.pin_pclk = 13; c.pin_vsync = 38; c.pin_href = 47;
  c.pin_sccb_sda = 40; c.pin_sccb_scl = 39; c.pin_pwdn = -1; c.pin_reset = -1;
  c.xclk_freq_hz = 20000000;
  c.pixel_format = PIXFORMAT_RGB565;
  c.frame_size = FRAMESIZE_96X96;        // small: 96x96 RGB565 = 18 KB per frame
  c.jpeg_quality = 12; c.fb_count = 1;
  c.fb_location = psramFound() ? CAMERA_FB_IN_PSRAM : CAMERA_FB_IN_DRAM;
  c.grab_mode = CAMERA_GRAB_LATEST;
  if (esp_camera_init(&c) != ESP_OK) return false;
  sensor_t *s = esp_camera_sensor_get();
  if (s) {
    s->set_hmirror(s, 1);                // mirror: looking at the panel feels like a mirror
    s->set_exposure_ctrl(s, 1); s->set_aec2(s, 1); s->set_ae_level(s, -2);   // auto exposure, biased dark
    s->set_gain_ctrl(s, 1); s->set_gainceiling(s, GAINCEILING_2X);           // no runaway gain in a dim room
    s->set_whitebal(s, 1); s->set_awb_gain(s, 1);
  }
  return true;
}

static uint8_t camLo = 0, camHi = 255;   // running black / white points of the frame (contrast stretch)
static void showCamera() {
  camera_fb_t *fb = esp_camera_fb_get();
  if (!fb) return;
  if (fb->format != PIXFORMAT_RGB565) { esp_camera_fb_return(fb); return; }
  int bw = fb->width / 8, bh = fb->height / 8;
  uint16_t *p = (uint16_t *)fb->buf;
  uint8_t cell[64][3]; int lo = 255, hi = 0; long sum = 0;
  for (int gy = 0; gy < 8; gy++) for (int gx = 0; gx < 8; gx++) {
    unsigned long r = 0, g = 0, b = 0; int n = 0;
    for (int y = gy * bh; y < (gy + 1) * bh; y += 2) for (int x = gx * bw; x < (gx + 1) * bw; x += 2) {
      uint16_t v = p[y * fb->width + x];
      v = (v >> 8) | (v << 8);           // RGB565 arrives big-endian from the sensor
      r += (v >> 11) & 0x1F; g += (v >> 5) & 0x3F; b += v & 0x1F; n++;
    }
    if (!n) n = 1;
    uint8_t *c = cell[gy * 8 + gx];
    c[0] = (r / n) << 3; c[1] = (g / n) << 2; c[2] = (b / n) << 3;
    int lum = (c[0] * 3 + c[1] * 6 + c[2]) / 10;
    if (lum < lo) lo = lum; if (lum > hi) hi = lum; sum += lum;
  }
  int fw = fb->width, fh = fb->height, ff = fb->format;
  esp_camera_fb_return(fb);
  // stretch the frame's own range to full: a flat frame (lens covered, saturated) goes dark instead of white
  camLo = (camLo * 3 + lo) / 4; camHi = (camHi * 3 + hi) / 4;
  int span = camHi - camLo; if (span < 24) span = 24;
  for (int i = 0; i < 64; i++) {
    int r = (cell[i][0] - camLo) * 255 / span, g = (cell[i][1] - camLo) * 255 / span, b = (cell[i][2] - camLo) * 255 / span;
    if (r < 0) r = 0; if (g < 0) g = 0; if (b < 0) b = 0;
    if (r > 255) r = 255; if (g > 255) g = 255; if (b > 255) b = 255;
    px.setPixelColor(idx(i % 8, i / 8), px.gamma32(px.Color(r, g, b)));
  }
  px.show();
  static uint32_t lastStat = 0;
  if (millis() - lastStat > 2000) { lastStat = millis(); Serial.printf("cam %dx%d fmt=%d lum min=%d mean=%ld max=%d stretch %d..%d\n", fw, fh, ff, lo, sum / 64, hi, camLo, camHi); }
}

// ---- heart: the ThinkOff logo's concentric colours, rippling from the core outwards ----
// Level per pixel: 0 = core ... 3 = heart edge, 4 = background (the logo's outermost band, drawn dim so the heart stands out).
static const uint8_t HEART_LEVEL[8][8] = {
  {4,3,3,4,4,3,3,4},
  {3,2,2,3,3,2,2,3},
  {3,2,1,0,0,1,2,3},
  {3,2,1,1,1,1,2,3},
  {4,3,2,1,1,2,3,4},
  {4,4,3,2,2,3,4,4},
  {4,4,4,3,3,4,4,4},
  {4,4,4,4,4,4,4,4},
};
// Logo colours from the centre out: white core, green, yellow, magenta, hot pink, pale pink (heart-v2 in WhereWatch PR #9)
static const int NPAL = 6;
static uint32_t PAL[NPAL] = {0xFFFFFF, 0x74D42C, 0xFFC400, 0xFF00E5, 0xFF3AD6, 0xFF8DE6};
static uint32_t heartBase = 0xFF8DE6;   // POST /api/color: replaces the pale pink (outermost) band
static float heartSpeed = 0.9f;         // bands per second travelling outwards

static uint32_t mixColor(uint32_t a, uint32_t b, float t, float k) {
  int r = (((a >> 16) & 0xFF) * (1 - t) + ((b >> 16) & 0xFF) * t) * k;
  int g = (((a >> 8) & 0xFF) * (1 - t) + ((b >> 8) & 0xFF) * t) * k;
  int bl = ((a & 0xFF) * (1 - t) + (b & 0xFF) * t) * k;
  return px.Color(r, g, bl);
}

static void showHeart(uint32_t now) {
  PAL[NPAL - 1] = heartBase;
  float phase = now / 1000.0f * heartSpeed;   // a colour born at the core reaches band d after d / heartSpeed seconds
  int step = (int)phase; float frac = phase - step;
  float pulse = 0.85f + loudPeak * 0.15f;      // sound only nudges the brightness
  for (int y = 0; y < 8; y++) for (int x = 0; x < 8; x++) {
    int lvl = HEART_LEVEL[y][x];
    int i0 = ((lvl - step) % NPAL + NPAL) % NPAL;        // colour currently on this band
    int i1 = ((lvl - step - 1) % NPAL + NPAL) % NPAL;    // the one arriving from the band inside
    float k = pulse * (lvl == 4 ? 0.3f : 1.0f);          // background band dim
    px.setPixelColor(idx(x, y), px.gamma32(mixColor(PAL[i0], PAL[i1], frac, k)));
  }
  px.show();
}

// ---- rainbow ----
static void showRainbow() {
  static uint16_t phase = 0;
  for (int y = 0; y < 8; y++) for (int x = 0; x < 8; x++) {
    px.setPixelColor(idx(x, y), px.gamma32(px.ColorHSV(phase + (x + y) * 2048)));
  }
  px.show();
  phase += 512;
}

// ---- web ----
WebServer web(80);
static bool wifiOk = false;
static const char PAGE[] PROGMEM = R"HTML(<!doctype html><meta name=viewport content="width=device-width,initial-scale=1"><title>ThinkOff Matrix</title>
<style>body{background:#0a0a0a;color:#eee;font-family:-apple-system,Helvetica,sans-serif;margin:0;padding:16px;text-align:center}
h1{color:#ff77ff;font-size:22px}button{background:#222;color:#eee;border:2px solid #ff00ff;border-radius:12px;padding:14px 18px;margin:6px;font-size:18px}
button.on{background:#ff00ff;color:#000}input[type=range]{width:80%}canvas{image-rendering:pixelated;width:240px;height:240px;border:1px solid #333;margin:12px}
label{display:block;margin-top:14px;color:#b0b0b0}</style>
<h1>ThinkOff Matrix</h1><div id=m><button onclick="set('mode?m=0')">rainbow</button><button onclick="set('mode?m=1')">heart</button><button onclick="set('mode?m=2')">camera</button></div>
<label>brightness <span id=bv></span></label><input id=b type=range min=4 max=160 oninput="set('brightness?v='+this.value)">
<label>heart colour</label><input id=c type=color value="#ff77ff" onchange="set('color?hex='+this.value.slice(1))">
<label>serpentine wiring</label><button id=s onclick="set('serpentine?v='+(st.serpentine?0:1))">flip</button>
<canvas id=cv width=8 height=8></canvas>
<script>let st={};async function set(q){await fetch('/api/'+q,{method:'POST'});load()}
async function load(){st=await (await fetch('/api/state')).json();document.querySelectorAll('#m button').forEach((b,i)=>b.className=i==st.mode?'on':'');b.value=st.brightness;bv.textContent=st.brightness;
const p=await (await fetch('/api/pixels')).json();const x=cv.getContext('2d');p.forEach((h,i)=>{x.fillStyle='#'+h;x.fillRect(i%8,(i/8)|0,1,1)})}
load();setInterval(async()=>{const p=await (await fetch('/api/pixels')).json();const x=cv.getContext('2d');p.forEach((h,i)=>{x.fillStyle='#'+h;x.fillRect(i%8,(i/8)|0,1,1)})},500)</script>)HTML";

// ---- modes ----
static int mode = 0;
static const char *MODE_NAME[3] = {"rainbow", "heart", "camera"};

static void announce() {
  Serial.printf("mode %d %s  mic=%s cam=%s serpentine=%d brightness=%d clap=%d\n", mode, MODE_NAME[mode],
                micOk ? "ok" : "off", camOk ? "ok" : "off", serpentine, brightness, clapEnabled);
}

static void indexTest() {                 // lights pixel 0..7 along the first row so the wiring order is obvious
  for (int i = 0; i < 8; i++) { px.clear(); px.setPixelColor(i, px.Color(255, 0, 180)); px.show(); delay(120); }
  px.clear(); px.show();
}

static void enterBootloader() {          // reboot into the ROM download mode so a flash never needs the B button
  Serial.println("rebooting into bootloader");
  Serial.flush(); delay(50);
  REG_WRITE(RTC_CNTL_OPTION1_REG, RTC_CNTL_FORCE_DOWNLOAD_BOOT);
  esp_restart();
}

static void sendState() {
  char buf[200];
  snprintf(buf, sizeof buf, "{\"mode\":%d,\"modeName\":\"%s\",\"brightness\":%d,\"serpentine\":%d,\"color\":\"%06X\",\"mic\":%d,\"cam\":%d,\"clap\":%d}",
           mode, MODE_NAME[mode], brightness, serpentine, (unsigned)heartBase, micOk, camOk, clapEnabled);
  web.send(200, "application/json", buf);
}

static void webSetup() {
  web.on("/", []() { web.send_P(200, "text/html", PAGE); });
  web.on("/api/state", HTTP_GET, sendState);
  web.on("/api/mode", HTTP_POST, []() { int m = web.arg("m").toInt(); if (m >= 0 && m < 3) mode = m; announce(); sendState(); });
  web.on("/api/brightness", HTTP_POST, []() { int v = web.arg("v").toInt(); if (v >= 1 && v <= 255) { brightness = v; px.setBrightness(brightness); } sendState(); });
  web.on("/api/serpentine", HTTP_POST, []() { serpentine = web.arg("v").toInt() != 0; sendState(); });
  web.on("/api/color", HTTP_POST, []() { String h = web.arg("hex"); if (h.length() == 6) heartBase = strtoul(h.c_str(), nullptr, 16); sendState(); });
  web.on("/api/clap", HTTP_POST, []() { clapEnabled = web.arg("v").toInt() != 0; sendState(); });
  web.on("/api/bootloader", HTTP_POST, []() { web.send(200, "application/json", "{\"ok\":1}"); delay(100); enterBootloader(); });
  web.on("/api/pixels", HTTP_GET, []() {
    String out = "["; out.reserve(64 * 9 + 2);
    for (int i = 0; i < N; i++) { uint32_t c = px.getPixelColor(i); char b[12]; snprintf(b, sizeof b, "%s\"%06X\"", i ? "," : "", (unsigned)(c & 0xFFFFFF)); out += b; }
    out += "]"; web.send(200, "application/json", out);
  });
  web.begin();
}

static void wifiSetup() {
  WiFi.mode(WIFI_STA); WiFi.setHostname("matrix");
  const char *ssids[2] = {WIFI_SSID_1, WIFI_SSID_2}; const char *pws[2] = {WIFI_PASS_1, WIFI_PASS_2};
  for (int i = 0; i < 2 && !wifiOk; i++) {
    if (!ssids[i][0]) continue;
    WiFi.begin(ssids[i], pws[i]);
    for (int t = 0; t < 40 && WiFi.status() != WL_CONNECTED; t++) delay(250);
    wifiOk = WiFi.status() == WL_CONNECTED;
  }
  if (!wifiOk) { WiFi.mode(WIFI_AP); WiFi.softAP("ThinkOff-Matrix"); }
  MDNS.begin("matrix");
  Serial.printf("wifi %s ip %s\n", wifiOk ? "joined" : "own network ThinkOff-Matrix", wifiOk ? WiFi.localIP().toString().c_str() : WiFi.softAPIP().toString().c_str());
  webSetup();
}

void setup() {
  Serial.begin(115200);
  pinMode(BTN_PIN, INPUT_PULLUP);
  px.begin(); px.setBrightness(brightness); px.clear(); px.show();
  I2S.setPinsPdmRx(42, 41);
  micOk = I2S.begin(I2S_MODE_PDM_RX, 16000, I2S_DATA_BIT_WIDTH_16BIT, I2S_SLOT_MODE_MONO);
  camOk = camInit();
  indexTest();
  wifiSetup();
  announce();
}

void loop() {
  web.handleClient();
  static uint32_t lastBtn = 0; static bool btnWas = true;
  bool btn = digitalRead(BTN_PIN);
  uint32_t now = millis();
  if (btnWas && !btn && now - lastBtn > 300) { mode = (mode + 1) % 3; lastBtn = now; announce(); }
  btnWas = btn;
  micSample();
  if (clapPending) {                       // double clap = next mode, with a short white blink as the acknowledgement
    clapPending = false; mode = (mode + 1) % 3;   // no flash: the mode change is the acknowledgement (petrus: "no all white")
    Serial.println("double clap");
    announce();
  }
  while (Serial.available()) {
    char ch = Serial.read();
    if (ch == 'r') mode = 0; else if (ch == 'h') mode = 1; else if (ch == 'c') mode = 2;
    else if (ch == 's') serpentine = !serpentine;
    else if (ch == 'k') clapEnabled = !clapEnabled;
    else if (ch == 'B') enterBootloader();
    else if (ch >= '1' && ch <= '9') { brightness = (ch - '0') * 12; px.setBrightness(brightness); }
    else continue;
    announce();
  }
  if (mode == 1) { showHeart(now); delay(20); }
  else if (mode == 2 && camOk) { showCamera(); delay(60); }
  else { showRainbow(); delay(40); }
}

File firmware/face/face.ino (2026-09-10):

// WhereWatch face: the ESP32-C3 0.42" OLED board as the pendant's display + hands.
//
// The XIAO ESP32S3 (the brain) talks to this board over one UART. This board
// only draws what it is told and drives two outputs on request. No Wi-Fi, no
// logic of its own, so it can never disagree with the brain.
//
// Wiring (4 wires): XIAO 3V3 -> V3, XIAO GND -> GD, XIAO D6 (TX) -> RX,
// XIAO D7 (RX) -> TX. RX/TX on this board are GPIO20/GPIO21 (UART0 pins;
// the USB port stays free for flashing and debug).
//
// Protocol: one text line per message, newline-terminated, 115200 baud.
//   plain text        -> appended as the newest line at the bottom (scrolls, 4 lines)
//   #clear            -> blank screen
//   #big <text>       -> one line in the large font (up to 6 characters), centred
//   #vib <ms>         -> vibration motor on for <ms> milliseconds (max 2000)
//   #gps 0|1          -> GNSS power switch off/on
//   #hold             -> keep the screen on (no auto-off) until #release
//   #release          -> allow auto-off again
//   #ping             -> replies "pong" on the port the ping came from (link check)
// The screen goes dark SCREEN_TIMEOUT_MS after the last message unless held,
// and shows "no link" if the brain has been silent for LINK_TIMEOUT_MS.
//
// Board variants: the 0.42" panel sits on GPIO5/6 (01Space v1) or GPIO8/9
// (later boards). Both pairs are probed at boot for a device at 0x3C.
//
// Build (CDCOnBoot=cdc is REQUIRED: without it arduino-esp32 puts Serial on
// UART0, whose default pins on the C3 are GPIO20/21, the very pins of the
// brain link; the guard around Serial.begin() below makes a plain build
// merely lose USB debug instead of the link):
//   arduino-cli compile --fqbn esp32:esp32:esp32c3:CDCOnBoot=cdc firmware/face
// Needs the U8g2 library. Upload with the board on USB-C:
//   arduino-cli upload -p /dev/cu.usbmodem* --fqbn esp32:esp32:esp32c3:CDCOnBoot=cdc firmware/face

#include <Arduino.h>
#include <Wire.h>
#include <U8g2lib.h>

static const uint32_t BAUD = 115200;
static const int UART_RX_PIN = 20;   // header "RX"
static const int UART_TX_PIN = 21;   // header "TX"
static const int VIB_PIN = 10;       // header "10": vibration module IN
static const int GPS_EN_PIN = 3;     // header "3": GNSS power switch control
static const uint8_t OLED_ADDR = 0x3C;
static const uint32_t SCREEN_TIMEOUT_MS = 8000;
static const uint32_t LINK_TIMEOUT_MS = 60000;
static const int ROWS = 4;
static const int COLS = 12;          // 6x10 font on a 72-pixel-wide panel

HardwareSerial Brain(1);
U8G2_SSD1306_72X40_ER_F_HW_I2C *oled = nullptr;

String rows[ROWS];
String bigText;
bool screenOn = true;
bool hold = false;
uint32_t lastMsgMs = 0;
uint32_t vibUntilMs = 0;

static bool probeI2C(int sda, int scl) {
  Wire.end();
  Wire.begin(sda, scl);
  Wire.beginTransmission(OLED_ADDR);
  bool found = (Wire.endTransmission() == 0);
  return found;
}

static void initDisplay() {
  const int pairs[2][2] = {{5, 6}, {8, 9}};
  for (auto &p : pairs) {
    if (probeI2C(p[0], p[1])) {
      oled = new U8G2_SSD1306_72X40_ER_F_HW_I2C(U8G2_R0, U8X8_PIN_NONE, p[1], p[0]);
      break;
    }
  }
  if (!oled) {
    // No panel answered: still run, so the UART side and the outputs work.
    return;
  }
  oled->begin();
  oled->setBusClock(400000);
  oled->setContrast(255);
}

static void redraw() {
  if (!oled) return;
  static bool asleep = false;
  if (!screenOn) {
    if (!asleep) { oled->setPowerSave(1); asleep = true; }   // panel really off, not just black
    return;
  }
  if (asleep) { oled->setPowerSave(0); asleep = false; }
  oled->clearBuffer();
  if (bigText.length()) {
    oled->setFont(u8g2_font_logisoso16_tf);
    int w = oled->getStrWidth(bigText.c_str());
    oled->drawStr((72 - w) / 2, 30, bigText.c_str());
  } else {
    oled->setFont(u8g2_font_6x10_tf);
    for (int i = 0; i < ROWS; i++) {
      oled->drawStr(0, 9 + i * 10, rows[i].c_str());
    }
  }
  oled->sendBuffer();
}

static void pushLine(const String &s) {
  bigText = "";
  for (int i = 0; i < ROWS - 1; i++) rows[i] = rows[i + 1];
  rows[ROWS - 1] = s.substring(0, COLS);
}

static void handle(String line, Stream &from) {
  line.trim();
  if (!line.length()) return;
  lastMsgMs = millis();
  screenOn = true;
  if (line[0] != '#') {
    pushLine(line);
    redraw();
    return;
  }
  int sp = line.indexOf(' ');
  String cmd = sp < 0 ? line : line.substring(0, sp);
  String arg = sp < 0 ? "" : line.substring(sp + 1);
  arg.trim();
  if (cmd == "#clear") {
    for (auto &r : rows) r = "";
    bigText = "";
  } else if (cmd == "#big") {
    bigText = arg.substring(0, 6);
  } else if (cmd == "#vib") {
    uint32_t ms = constrain(arg.toInt(), 0, 2000);
    digitalWrite(VIB_PIN, HIGH);
    vibUntilMs = millis() + ms;
  } else if (cmd == "#gps") {
    digitalWrite(GPS_EN_PIN, arg.toInt() ? HIGH : LOW);
  } else if (cmd == "#hold") {
    hold = true;
  } else if (cmd == "#release") {
    hold = false;
  } else if (cmd == "#ping") {
    from.println("pong");              // answered where it came from (UART or USB)
  }
  redraw();
}

void setup() {
  pinMode(VIB_PIN, OUTPUT);
  digitalWrite(VIB_PIN, LOW);
  pinMode(GPS_EN_PIN, OUTPUT);
  digitalWrite(GPS_EN_PIN, LOW);      // GNSS off until the brain says otherwise
  Brain.begin(BAUD, SERIAL_8N1, UART_RX_PIN, UART_TX_PIN);
#if ARDUINO_USB_CDC_ON_BOOT
  Serial.begin(BAUD);                 // USB CDC, debug only (never UART0: that would steal GPIO20/21)
#endif
  initDisplay();
  pushLine("WhereWatch");
  pushLine(oled ? "face ready" : "no panel");
  pushLine("waiting...");
  lastMsgMs = millis();
  redraw();
}

void loop() {
  static String buf;
  while (Brain.available()) {
    char c = (char)Brain.read();
    if (c == '\n' || c == '\r') {
      if (buf.length()) handle(buf, Brain);
      buf = "";
    } else if (buf.length() < 120) {
      buf += c;
    }
  }
  // Same protocol on USB, so the face can be tried from a computer alone.
#if ARDUINO_USB_CDC_ON_BOOT
  while (Serial.available()) {
    char c = (char)Serial.read();
    static String ubuf;
    if (c == '\n' || c == '\r') {
      if (ubuf.length()) handle(ubuf, Serial);
      ubuf = "";
    } else if (ubuf.length() < 120) {
      ubuf += c;
    }
  }
#endif
  uint32_t now = millis();
  static bool linkLost = false;
  if (vibUntilMs && (int32_t)(now - vibUntilMs) >= 0) {
    digitalWrite(VIB_PIN, LOW);
    vibUntilMs = 0;
  }
  if (screenOn && !hold && !linkLost && now - lastMsgMs > SCREEN_TIMEOUT_MS) {
    screenOn = false;
    redraw();
  }
  if (!linkLost && now - lastMsgMs > LINK_TIMEOUT_MS) {
    linkLost = true;
    screenOn = true;
    pushLine("no link");
    redraw();                          // stays up: the auto-off below skips while linkLost
  } else if (linkLost && now - lastMsgMs < LINK_TIMEOUT_MS) {
    linkLost = false;                  // handle() already reset lastMsgMs on the new message
  }
  delay(5);
}

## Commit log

2026-08-13 WhereWatch: design README - the pendant that remembers where things went
    petrus (room, Aug 13): ESP32-S3+OV5640 pendant, 2fps/stills dual mode, Frigate
    filter + local Qwen-vision indexer on a Pi, 'where are my keys' answered with
    the last photo containing them. Status honestly: design stage, nothing built.
2026-08-13 design: motion-gated transmission (petrus) - frame-diff on device, optional IMU; radio off when nothing moves
2026-08-13 design: lens-cover pause + trigger-only voice tags (petrus) - whisper-transcribed notes pinned to the index
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2026-08-13 hardware: draft BOM (petrus asked) - pendant ~40-55e, XIAO ESP32S3 Sense as lead candidate, open questions marked [verify]
2026-08-13 design: haptic status (petrus) - double-tap buzz codes, coin vibration motor as the sole output
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2026-08-13 hardware: board PICKED - XIAO ESP32S3 Sense + OV5640 connector module (swap compatibility confirmed in Seeed listing)
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2026-08-13 design: more use cases on the same index (petrus) - told-not-seen notes from chat/button, did-I checks, running-low, before/after
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2026-08-13 architecture: the database - SQLite schema (episode + FTS5 + current_state), every question family one query
2026-08-13 architecture: apply codex review - fail-closed blur, opt-in posting, tile metadata, hashed BSSIDs, GNSS no-fix, FTS5 triggers, current_state (object,kind), deterministic answer rule
2026-08-13 architecture: Pi uses stock case, glue-on display; only the pendant is a custom print (petrus)
2026-08-13 architecture: pendant printed QR = finder-safe RETURN page only; dashboard reached separately/auth-gated (petrus idea, privacy split)
2026-08-13 architecture: Pi doubles as pendant dock - USB-A out charges + wired sync on one cable; any USB-C charger as fallback (petrus)
2026-08-13 architecture: optional printed display-shroud + pendant-cradle clip-on for the stock Pi case (petrus); parametric, product works without
2026-08-13 cost: BOM + pricing notes (petrus) - ~200e prototype / ~130e volume core build; three pricing models; no-subscription tension
2026-08-13 architecture: concrete first-run sequence for a pre-paired kit (petrus) - power base, pendant on dock, scan wifi QR
2026-08-13 architecture: storage math (petrus) - 5MP stills ~0.5-2GB/day, 256GB SSD ~4-12 months; display shows charge + storage headroom; RAM vs disk clarified
2026-08-13 cad: parametric pendant enclosure skeleton (openscad) + cad README; design: status-display mockup (petrus asked for shape + sample pic)
    [pendant.scad]
2026-08-13 web: device colourway themes the whole UI (petrus) - 5 swatches, persisted, accent drives buttons/tabs/highlights; colorway swatch art; verified in browser
2026-08-13 architecture: status display themes to device color + shows ThinkOff heart on non-black variants (petrus)
2026-08-13 architecture: detachable e-ink Badger display (petrus) - docks as status face, detaches as a zero-power carry message board; vs fixed backlit color face
2026-08-13 web+design: retention default = keep-until-full ring buffer (petrus), optional cap off by default; map never Google - OSM offline/Pi-proxied tiles; null-safe settings wiring
2026-08-13 privacy: remove pricing/BOM/margin from public repo (petrus) - COST.md + SHOPPING.md now private; scrub euro figures from HARDWARE.md + ARCHITECTURE.md, keep the decisions
2026-08-14 cad: render pendant preview PNG + export STL (petrus asked to see the CAD) - installed openscad, skeleton shape visible: camera hole, lanyard loop, USB-C cutout
    [pendant.stl]
2026-08-14 cad: rounded PEBBLE pendant (petrus) - 80x35x10mm smooth, fully rounded, no sharp corners; camera lens near one end; hull-of-spheres form, STL exported, shape preview rendered
    [pendant.scad, pendant.stl]
2026-08-14 cad: friendly pebble v2 (petrus) - extra-domed top, camera+lanyard at top, battery bay in bottom half, 3 emoji badge recesses on back; battery fit math in comments
    [pendant.scad, pendant.stl]
2026-08-14 cad: personalised 2Ah pebble (petrus) - size derived from the 654060 cell (88x45x11, still 11mm thin), flat signet pad + engrave_text/engrave_svg params, fuchsia render (never blue)
    [pendant.scad, pendant.stl]
2026-08-16 docs: name CodeWatch as the WhereWatch companion board
    One sentence for a fresh 118 dashboard card.
2026-08-16 pendant: elongated thin profile per petrus's Aug 16 spec
    Case-first design: the shell decides the form, the cell is chosen to
    fit (petrus: 'emme valitse koteloa akun perusteella vaan akun kotelon
    perusteella'). Faces thinned to 1.2 mm so total thickness is ~2.4 mm
    over the cell; sensor zone documented top-down - GPS ceramic at the
    tip beside the XIAO (they fit side by side, camera and IMU stack in
    the thickness axis), battery keeps a full-length bay below. Adds a
    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
    [pendant.scad]
2026-08-16 pendant v2: teardrop - narrow round tip, wide rounded-corner bottom
    petrus: 'ylaosasta kapea ja pyorea, alhaalta leveampi pyoristetyilla
    kulmilla'. The taper mirrors the parts: GPS patch alone needs the
    16 mm tip, the cell defines the 43 mm bottom. Sensor zone runs in
    line down the taper (GPS, camera, XIAO with the IMU stacked in Z),
    cell bay starts ~12 mm above the base so its square corners clear
    the corner radius. 22 / 43 / ~102 / 9.3 mm.
    [pendant.scad]
2026-09-01 Add BUILD.md: pendant build checklist (solder order: battery pads, IMU, button, vibration, camera last)
2026-09-02 BUILD.md: electrical corrections from review (driver module or ~1 kOhm base resistor, battery divider for the ADC, header clipping before the case, polarity typo)
2026-09-08 BUILD.md: GNSS + 0.42" OLED steps, pin map for the XIAO ESP32S3 Sense
    petrus (8 Sep): the GPS module, the 0.42" 72x40 OLED and a second mic are
    now in the parts box, and the small face goes ON the pendant ("the 0.4
    inch is not too much display"). The checklist had no step for either and
    no pin map at all.
    - step 0: GNSS is in hand (not optional); the 0.42" panel must be the bare
    4-pin I2C module, the purple ESP32-C3 board carrying the same panel is a
    second MCU and stays out of the pendant; the Sense's PDM mic covers audio.
    - 2b OLED on the shared I2C (dark by default, lit on tap/flick, window+lip
    in the case); 2c GNSS on the spare UART with the home/away power rule.
    - Pin map table w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
2026-09-08 BUILD.md pin map: D2/GPIO3 is spare; the Sense SD-card CS is GPIO21 (claudemm review, Seeed sense_filesystem page)
2026-09-08 ASSEMBLY.md: plain-words assembly guide for the first pendant
    petrus (8 Sep): "So now I need very easy assembly instructions". BUILD.md
    is the technical checklist; this is the page to follow at the table: nine
    steps, one part each, label-to-label wiring tables, a visible check per
    step, USB power first and the single solder joint (battery lead with the
    slide switch in the red wire) last. Pin labels match the pin map in PR #4
    (D4/D5 I2C shared by motion sensor and OLED, D6/D7 UART for GPS, D1
    button, D3 vibration).
2026-09-08 BUILD.md 2c: GNSS power through a D2-controlled load switch, not the always-on 3V3 (codex P2)
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2026-09-08 firmware/face: the ESP32-C3 0.42" OLED board as the pendant's face
    petrus (8 Sep): "I'd like to use the small one". The purple ESP32-C3 board
    with the 0.42" panel becomes a UART helper: it draws the text lines the
    XIAO sends (4 scrolling rows, or one big centred word), buzzes the
    vibration module from its pin 10 (#vib ms), switches the GNSS power from
    its pin 3 (#gps 0|1), goes dark 8 s after the last message, and shows
    "no link" after a minute of silence. Probes both known panel wirings
    (GPIO5/6 and GPIO8/9) at boot. Same protocol on USB, so it can be tried
    from a computer alone.
    Compiled with arduino-cli, esp32 core 3.3.11, U8g2 2.36.19, fqbn
    esp32:esp32:esp32c3 (CDC on boot): 26% flash,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
    [face.ino]
2026-09-08 face.ino: Serial only as USB CDC (guarded), "no link" stays visible, panel power-save when dark (claudemm review)
    P1: a plain esp32c3 build put Serial on UART0 = GPIO20/21, the brain link's pins; Serial.begin is now guarded by ARDUINO_USB_CDC_ON_BOOT and the header states the required fqbn. P2: the auto-off skipped while linkLost so "no link" no longer blanks 5 ms after it appears. Minor: setPowerSave on blank/wake.
    [face.ino]
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2026-09-10 play-matrix: logo heart ripple, strict double clap, no white flash, camera contrast stretch, serial bootloader entry
    - heart: the ThinkOff logo palette (white core, green, yellow, magenta, hot pink, pale pink)
    travelling from the core outwards, background as the outermost dim band (petrus 16:09Z)
    - double clap: two sharp onsets 150-600 ms apart with quiet between, 2 s lockout; serial k /
    POST /api/clap toggles it (it was flipping modes on room noise)
    - no white acknowledgement flash on a mode switch (petrus: "no all white")
    - camera: auto exposure biased dark, gain ceiling 2x, per-frame contrast stretch so a covered
    or saturated lens goes dark instead of white; frame stats on serial ev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
    [play-matrix.ino]
2026-10-07 Base station v0: photos in, where-is-it answers out
    A standard-library Python base station that makes the web app's /api/*
    answer from real photos instead of mock.js: photos dropped into an inbox
    are read by a local vision model (OpenAI-compatible llama-server with an
    mmproj, tested with Qwen3-VL-8B), the things and where they lie go into
    SQLite, and /api/ask, /api/objects, /api/timeline, /api/status and
    POST /api/retention serve from it.
    Things, not people: the prompt skips people and anything worn or held,
    sightings whose name or position mention a person are dropped, and
    test_base.py pins the filter.
2026-10-07 Blur faces before a photo is stored
    petrus's decision on PR #16: the index already holds no people, and now
    the evidence photos do not show faces either. The vision model is asked
    for every face/head box; each is padded, pixelated and blurred, and the
    unblurred original is never kept. If people are reported without usable
    boxes, or the face check fails, the whole photo is blurred (fail closed).
    Metadata is dropped on save. Pillow becomes the one dependency.
    Tested: the person photo in the CC test set is stored with the face
    unrecognisable and the rest intact; 4 new unit tests (box scaling and
    clamping, fail-closed cases, only the face region changes).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
2026-10-07 Fail closed on malformed face answers; retention never orphans a file
    Rest of codexmb's review of #16:
    - face_boxes now accepts only the asked shape (boolean people, list
    faces). A missing or invalid people/faces, or boxes sent but none
    usable, means unknown: the whole photo is blurred. Before, an answer
    without "people" counted as "no faces".
    - Retention deletes the file first and keeps the index rows if that
    fails, so the next pass retries instead of leaving an untracked photo.
    - The people filter is now described as lowering the risk, not a
    guarantee: English words only, so names and other languages pass.
    Tests: 15 (new: wrong-shape answers fail closed, retention retry).
    Co-Au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
2026-10-09 Recap: word allowlist, per-thing digest, shared model calls, honest card
    Fixes from an adversarial review of the first commit (each reproduced
    before fixing):
    - The model's answer is shown only if every word is a time, a word from that
    day's thing names, places and positions, or a small fixed narrative
    vocabulary (RECAP_WORDS). The English person-word list alone let names,
    family words, reflexives and other languages through.
    - The digest collapses repeats per thing, not per adjacent row: photos with
    two things alternated and overflowed RECAP_LINES, dropping earlier moves.
    - Leftover reasoning (a lone </think> from templates that open <think> in
    the prompt, or a cut-off <think>) n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
